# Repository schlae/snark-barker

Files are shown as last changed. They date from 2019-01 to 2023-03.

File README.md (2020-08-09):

# The Snark Barker - a SB 1.0 Clone

The Snark Barker is a 100% compatible clone of the famed SB 1.0 "Killer Card"
sound card from 1989. It implements all the features, including the digital
sound playback and recording, Ad Lib compatible synthesis, the joystick/MIDI
port, and the CMS chips (which are actually Philips SAA1099 synthesizer
devices).

Snark Barker photo

All of the components are readily available. In the bill of materials,
Mouser part numbers are listed where they are available. Chips not available
from Mouser can be purchased from a variety of sources in China.

[Schematic](https://github.com/schlae/snark-barker/blob/master/SnarkBarker.pdf)

[Bill of Materials](https://github.com/schlae/snark-barker/blob/master/SnarkBarker.csv)

Please note that the 0.1" header pins are *not* listed on the BOM. They are
standard breakaway headers (both single and double row). Jumper shunts are
also not listed on the BOM.

[Fab files](https://github.com/schlae/snark-barker/blob/master/fab/SnarkBarker.zip)

Board dimensions are 9.1 x 4.2 inches. When ordering the board, you may want
to specify a card edge bevel (fairly cheap!) and selective gold plating
(expensive!) depending on your needs. The soldermask color can be whatever
you like, but hot pink is preferred.

## The Volume Knob
There don't seem to be any off-the-shelf knobs compatible with the Alps
potentiometer. You may be able to 3D print one based on the model below.
I'd recommend using a high-resolution SLA printer like the Formlabs Form 2.

Fasten it to the potentiometer using an M1.4x0.3mm thread, 6mm long screw
(McMaster-Carr part number 91800A036 or equivalent).

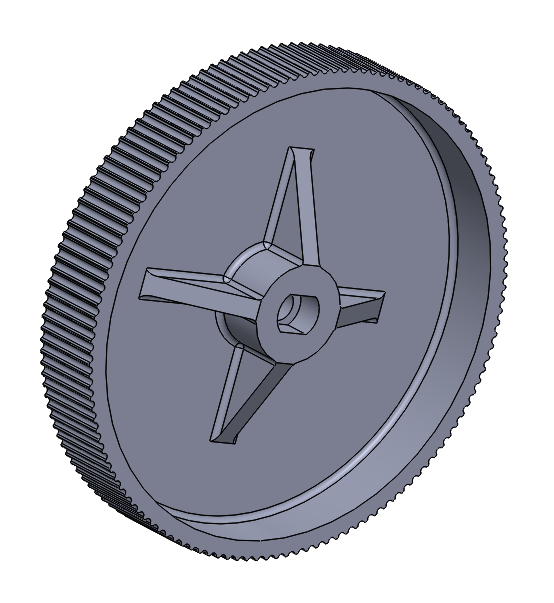
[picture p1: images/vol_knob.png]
Image of the volume knob


[Volume knob STEP model](https://github.com/schlae/snark-barker/blob/master/mech/vol_knob.zip)

Update: I've added a modified volume knob that may print better on FDM
printers.

[Volume knob STEP model, FDM version](https://github.com/schlae/snark-barker/blob/master/mech/vol_knob_fdm.zip)

## The ISA Card Bracket
The bracket specified in the BOM is a blank Keystone 9200 bracket. You will
need to punch or drill holes for the connectors. The KiCad board file has
detailed dimensions showing where to make the holes in the bracket.

I use a chassis nibbler tool to make the square slot for the volume knob as
well as the hole for the DA-15 joystick/MIDI connector. If you are rich,
Greenlee makes a punch for the DA-15 outline.

## The Firmware
There are two ways to get a programmed 80C51 chip for the Snark Barker. One
is to purchase a SB 2.0 DSP chip from China and put it in a 44-PLCC to
40-DIP adapter. This works fine and provides the largest feature set.

Another option is to buy a blank Atmel 89S51 (as listed in the BOM) and
program it with [this HEX file](https://github.com/schlae/snark-barker/blob/master/firmware/sb.hex).

## Assembly Notes
You may wish to socket the two CMS chips, the 80C51 microcontroller, and the
two Yamaha chips.

Be sure to add the 4.7K ohm bodge resistor on top of U5, running between
pins 4 and 14. (Shown below.)

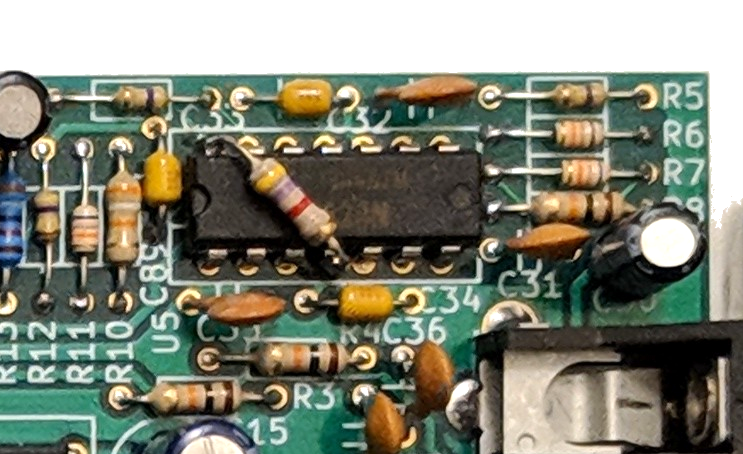
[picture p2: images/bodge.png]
Photo of bodge resistor


For MIDI to work properly, you'll need to solder jumper wires on the headers
marked TXD and RXD (next to the SNARK BARKER logo). Originally these two 3-pin
headers may have been used as a debug port.

Be sure to place shunts in the jumpers marked DRQ1 and JP1, to enable DMA and
the joystick, respectively. Also place shunts to configure the I/O address and
IRQ.

## Testing and Diagnostics
Test your shiny new card using your favorite PC games, or use the [SBDIAG
program that I've written](https://github.com/schlae/snark-barker/tree/master/sbdiag).

## Other Notes
Like the original SB 1.0, the Snark Barker does not need a -5V rail.

## License
This work is licensed under a Creative Commons Attribution-ShareAlike 4.0
International License. See [https://creativecommons.org/licenses/by-sa/4.0/](https://creativecommons.org/licenses/by-sa/4.0/).

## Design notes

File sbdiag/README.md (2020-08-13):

# The Snark Barker Diagnostic Program
Have you built a Snark Barker but it doesn't work right? Having trouble
figuring out exactly what is wrong? SBDIAG may be able to help!

## Usage
* Download the executable along with TADA.WAV and copy it to your vintage
system.
* Run SBDIAG.EXE
* Hit the number keys to pick a menu option
* Hit escape to go up one menu level or to quit.

## Troubleshooting
Unlike games and other software SBDIAG makes no assumptions about what is or
is not working on the hardware. The following few sections provide some basic
troubleshooting advice, primarily geared towards the Snark Barker, although
SBDIAG can be used with any Sound Blaster compatible sound card. It helps
to have the [schematic](https://github.com/schlae/snark-barker/blob/master/SnarkBarker.pdf) in front of you so you can follow along.

### SB DSP
The DSP is actually an 8051 microcontroller. It communicates with the host PC
using two latches that form a simple mailbox.

The first test on the menu, **DSP Address Test**, allows you to check the
address decode circuitry on the sound card. Run the test, and put a logic
probe or oscilloscope on pin 10 of U8 to confirm that the DSPRD\_CS# signal
is pulsing. You can also check pin 3 of U16 for the CARD\_SELECTED# signal.
Furthermore, check pin 3 of U27 to make sure ISA\_RD# is pulsing.

The **DSP Write Test** just writes the "disable speaker" command
in a loop. You can check pin 11 uf U18 (ISA\_WRITE#) to make sure the control
logic is sending the signal to the mailbox latch. If the DSP is alive, then
pin 1 of U18 (DSP\_READ#) will assert when the DSP tries to read the command.
Check pin 28 of U13 for the DAV\_DSP signal, which lets the DSP know that a
byte is waiting for it in the mailbox.

**DSP Reset** does what it says, pulsing the reset line on the DSP (pin 9 of
U13). If you don't see such a signal, backtrack through the reset logic of
U29, U30, U26, and W24.

**DSP Version** retrieves the two-byte version number of the DSP firmware.
If this returns a number that makes sense (like 2.02) then you know that the
DSP mailbox is working and the DSP is programmed correctly.

**DSP Interrupt** tests the interrupt logic by commanding the DSP to assert
the IREQUEST line (pin 12 of U13). You should see this line pulsing during the
test. You can also check pin 9 of U26 which is the actual interrupt line. The
RD\_DAV# line, is pulsed when the host PC tries to read 2xEh (the data
available flag) which clears the interrupt flag. This is pin 9 of U28.

**Generate Sine Wave (no DMA)** uses a DSP diagnostic command to generate a
sine wave. This test does not require working a working interrupt or DMA. You
 should hear a tone coming out of the speakers. If not, work your way through
the audio chain starting from U4, R4/R3, U5 (pin 1), and U5 (pin 8). The DAC
(U12) is current based so you will not see audio voltages on the output pin.
You can check for pulses on the incoming data lines (pins 5-12 of U12).

**Generate Sine Wave (DMA)** streams a digitally-generated sine wave to the
DSP using DMA and the interrupt. If you can hear this, then the digital section
of the card is working. If you hear it for 1 second and then silence, the
interrupt is not working.

**Play Digital Audio** this plays a familiar sound through the speaker. :-)

### Ad Lib Tests

The Ad Lib section of the card uses the YM3812 and Y3014 chips to play back
FM-synthesized audio. The **Try to Detect Ad Lib** menu option runs the
traditional detection algorithm that uses the YM3812's internal timer to
set a status bit. This is a good way to check U9's CS# (pin 7),
READ# (pin 6), WRITE# (pin 5), and A0 (pin 4) signals on the YM3812. While
you are there, make sure there is a 3.58MHz square wave on pin 24. If you
don't see a signal on one of those pins, work your way back through the logic
that drives those pins.

**Play Sine Wave** uses the YM3812 to generate a basic 1KHz sine wave. If you
don't hear anything but the Ad Lib was detected OK, check the audio path
starting from the digital CLOCK (U10 pin 5), LOAD (U10 pin 3) and SD (U10
pin 4) signals, moving to the audio output (U10 pin 2), buffer (U11 pin 14),
and mixer (U11 pins 8 and 7). The YM3812 registers are written only once, so
this test is not very useful for checking the YM3812's host interface.

**Play Percussion Loop** is meant for checking digital writes to the YM3812
registers. There are no read operations during this test.

### CMS Chip Tests

The CMS chips (optional) provide Game Blaster compatibility. If you have
installed them, this part of SBDIAG can help you test it. Since the chips
are write-only, SBDIAG has no way to confirm any tests; you will have to
check pins using a logic probe or oscilloscope, or listen for the audio
output.

**Write Loop** tests simply write to a CMS register over and over again. You
will not hear any sound but you can probe for activity on the following pins:

* CS# (pin 2)
* WR# (pin 1)
* A0 (pin 3)
* DTACK# (pin 7)

**Sine Wave** tests generate a 1KHz sine wave through the left channel, right
channel, or both channels at once. These tests write to the registers only
twice, once before the test and once afterwards to shut off the sound, so this
test is not very useful for use with a logic probe.

### SB-MIDI Tests
The Snark Barker, just like older Sound Blaster cards, has a very basic SB-MIDI
mode (not MPU-401 compatible). Not a whole lot of software uses it and the
wiring is incredibly simple (basically just 8051 UART lines wired to the
joystick port). The tests are very simple and just test the port output and
input capabilities. Note that the loopback test will occasionally return
bad values even when it is working OK.

### Joystick Tests
The PC joystick port is very basic and uses a quad timer chip along with a
simple resistor-capacitor circuit to measure the resistance of the joystick
potentiometers.

**Get raw port status** just returns the raw bits that it reads from the
joystick port. If you have a socketed NE558, you can remove it from the socket
and manually jumper the U3 inputs (pins 2, 4, 6, 8, 11, 13, 15, and 17) to
ground in order to verify that the U3 buffer is working and that the address
hardware also works. You can check U3 pin 1 to verify that the address
decoder is working. Also, joystick buttons can be tested in this state.

**Measure joystick potentiometers** performs the standard PC joystick algorithm
and returns the raw counter values for each axis. You can check that the
trigger signal is correctly appearing at the NE558 by checking pin 3 of U1.

## Building
If you want to build SBDIAG, use Borland Turbo C++ version 3.1 under DOS. Be
sure to set the memory model to "large" or it will not be able to play back
digital audio. This program will run in DOSBOX or on a real vintage computer.

## License
This work is licensed under a Creative Commons Attribution-ShareAlike 4.0
International License. See [https://creativecommons.org/licenses/by-sa/4.0/](https://creativecommons.org/licenses/by-sa/4.0/).

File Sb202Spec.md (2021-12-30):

# Snark Barker 2.02 DSP Firmware Specification

This document is a work in progress. It is an attempt to describe in detail the
operation of the Sound Blaster DSP 2.02 firmware. It's not meant to introduce
you to how Sound Blaster cards play back and record audio, but to describe
how the DSP 2.02 firmware itself works, including previously unknown and
undocumented commands.

Some of the previously undocumented commands and features include:
* The RAM playback command, which loads up to 64 samples into RAM and plays
them back over the speaker.
* The RAM test command, which runs a very basic RAM test on the 8051's
internal SRAM.
* The ROM checksum command, which adds up the contents of ROM into a 16-bit
checksum and returns it (with the two bytes swapped!) to the host PC.

# Pin Assignment Table
| Pin | GPIO | Net | Dir | Description |
| --- | ---- | --- | --- | --- |
| 1 | P1.0 | DAC LSB | O | LSB going to DAC output 
| 2 | P1.1 | DAC | O |
| 3 | P1.2 | DAC | O |
| 4 | P1.3 | DAC | O |
| 5 | P1.4 | DAC | O |
| 6 | P1.5 | DAC | O |
| 7 | P1.6 | DAC | O |
| 8 | P1.7 | DAC MSB | O | MSB going to DAC output
| --- | ---- | --------- | --- |
| 10  | P3.0 | MIDI RX | I | MIDI receive data in
| 11  | P3.1 | MIDI TX | O | MIDI transmit data out
| 12  | P3.2 | IREQUEST\# | O | Pulse low to turn on IRQ to PC
| 13  | P3.3 | DSP\_BUSY | O | Set high to tell PC we are busy
| 14  | P3.4 | DMA\_EN\#  | O | Set low to enable DMA requests
| 15  | P3.5 | DREQUEST  | O | Pulse high to ask PC DMA for more data
| 16  | P3.6 | DSP\_WRITE\# | O | (8051 auto sets this to send data to PC)
| 17  | P3.7 | DSP\_READ\#| O | (8051 auto sets this to get data from PC)
| --- | ---- | --------- | --- |
| 21  | P2.0 | MUTE\_EN  | O | Bring high to mute speaker output
| 22  | P2.1 | N/C | |
| 23  | P2.2 | N/C | |
| 24  | P2.3 | N/C | |
| 25  | P2.4 | N/C | |
| 26  | P2.5 | MIC\_COMP | I | Status of mic input: 1=mic \< DAC, 0=mic \> DAC
| 27  | P2.6 | DAV\_PC | I | 1=Data waiting in buffer for PC host to read it
| 28  | P2.7 | DAV\_DSP  | I | 1=Data waiting in buffer for 8051 to read it

## Detailed Pin Descriptions

### IREQUEST
Initial state: high.

Setting this pin low and then high will trigger an interrupt to be sent
to the host PC.

### DREQUEST
Initial state: low.

Set this pin high and then low to trigger a DMA request to be sent to
the host PC.

### DSP\_BUSY
Initial state: high.
Set this pin low when the firmware is ready to receive commands or command
arguments from the host. This pin should be set high while in interrupt
handlers and cleared at the end of the interrupt handler. It should also
go high when a command is received, at least until the command is successfully
latched into the command holding register.

Here's an example sequence.

1. START: set DSP\_BUSY high
2. Preparation, initialization
3. Ready to receive commands. Set DSP\_BUSY low.
4. Command received from host PC. Set DSP\_BUSY high.
5. Parse command byte, dispatch to correct command handler.
6. Command handler requires an argument byte. Set DSP\_BUSY low.
7. Argument byte received from host PC. Set DSP\_BUSY high.
8. Execute command.
9. Done. Go back to waiting for new commands. Set DSP\_BUSY low.

### DMA\_EN\#
Initial state: high.
Pull this pin low to unmask DMA channel requests. This allows the PC's
8237 to transfer data to or from the sound card.

Typically this pin is pulled low when the firmware is ready transfer data
to the host PC. Set the pin high when the entire transfer is completed--i.e.
you run out of samples to play back.

### DSP\_WRITE\# and DSP\_READ\#
These pins are used by the 80C51's external memory access circuitry to
transfer data during a MOVX instruction. They do not need to be touched
at all by firmware.

### MUTE\_EN
Initial state: low

Assert this line high to prevent the DAC output voltage from reaching the
speaker amplifier.

Note that muting and unmuting the DAC output requires a process to prevent
audible pops. See the speaker mute and unmute commands. This line is controlled
only by those two routines (and the start routine that sets it low on boot). 

### MIC\_COMP
This is an input from the microphone input comparator. It outputs a 1 when
the input sample is less than the current DAC value. It outputs a 0 when the
input sample is greater than the current DAC value. It's checked with the
special ADC successive approximation sampling routine.

### DAV\_PC
This pin is high when data is sitting in the output register but the host PC
has not yet picked it up. The pin goes low when the PC reads the data.

By writing to the external output register using movx, this pin automatically
gets set by the hardware.

### DAV\_DSP
This pin goes high when there is data available in the input register from the
host PC. Otherwise, it remains low until the host PC writes to it.

When reading from the external input register using movx, this pin
automatically gets cleared by the hardware.

# List of DSP Commands

Commands are divided into logical groups.

| Upper Nibble | Command Group  |
| --- | --- |
| 0 | Status |
| 1 | Playback |
| 2 | Recording |
| 3 | MIDI |
| 4 | Transfer setup |
| 5 | Playback (RAM) |
| 6 | Reserved |
| 7 | Playback 2 |
| 8 | Silence |
| 9 | Playback (High Speed) |
| A | Reserved |
| B | Reserved |
| C | Reserved |
| D | Miscellaneous  |
| E | Version |
| F | Test |

Each command group checks individual bits in the lower nibble. The checks
often have a priority; entries at the top of the table get executed if the bit
is set, and entries with lower priorities get ignored even if their bits are
set.

Arguments listed for particular commands are single byte only. Often values
are split into high and low bytes.

## Status Group (0x0)
| Lower Nibble Bit | Command | Description
| --- | --- | ---
| 3 | Halt | Enters an infinite loop.
| 2 | Status  | Sends status flags to the host PC. If DMA\_ENABLE\# is low, then the command reenables the timer interrupt.

## Playback Group (0x1)
| Lower Nibble Bit | Command | Argument | Description
| --- | --- | --- | ---
| 3 | Autoinit DMA DAC | None | Starts auto-init DMA playback
| 2 | DMA DAC | Length lo, length hi |Starts regular DMA playback of "length" samples.
| All others | Direct DAC | byte | Immediately loads DAC with provided sample byte

The above DMA commands check additional bits of the command byte as follows:

| Lower Nibble Bit | Description
| --- | ---
| 1 | 1=Use 2-bit ADPCM compression, 0=Normal 8-bit uncompressed samples
| 0 | Read additional argument byte, use as starting reference for ADPCM

## Recording Group (0x2)
| Lower Nibble Bit | Command | Argument | Description
| --- | --- | --- | ---
| 3 | Autoinit DMA ADC | None | Starts auto-init DMA recording
| 2 | DMA ADC | Length lo, Length hi | Starts regular DMA recording
| All others | Direct ADC | None | Immediately reads a sample from the microphone input and returns it as a byte

## MIDI Group (0x3)

| Lower Nibble Bit | Command | Argument | Description
| --- | --- | --- | ---
| 3 | MIDI Write Poll | MIDI byte | Sends provided byte out over MIDI port
| 2 | MIDI UART mode | none | Ignores DSP commands until a DSP RESET. All subsequent data is piped through MIDI in both directions.
| All others | MIDI Read Poll | none | Receives data from MIDI port, returns the raw bytes. End command by sending any byte to the DSP.

The above MIDI commands check additional bits of the command byte as follows:

| Lower Nibble Bit | Description
| --- | ---
| 1 | Timestamp mode. Adds a 24-bit timestamp to the start of the read data that records the time passed since the command started.
| 0 | Interrupt mode. Generates an interrupt if MIDI read data is available.

## Setup Group (0x4)
| Lower Nibble Bit | Command | Argument | Description
| --- | --- | --- | ---
| 3 | Set DMA block size | block len low, block len high | Sets up DMA block length
| All others | Set time constant | time constant | Sets the sample timer to the provided time constant.

## RAM Playback Group (undocumented) (0x5)
| Lower Nibble Bit | Command | Argument | Description
| --- | --- | --- | ---
| 3 | RAM Load | number of ram samples, ram playback count low, ram playback count high, unused, \<samples\> | Loads RAM with samples to play back, up to 64 bytes.  Playback count is the number of times the sample is repetitively played back in a loop.
| 0 | RAM Playback | none | Plays back samples in RAM

The "ram samples" argument contains the number of samples loaded into RAM.
The playback count (high and low) variables tell the sound card how many times
to play back the RAM sample.

## Reserved (0x6, 0xA, 0xB, 0xC)
The reserved command groups fall through to the status group 0 handler *iff* 
the DMA\_ENABLE\# pin is low. Otherwise the command is ignored and the
firmware waits for further commands from the DSP.

## Second Playback Group (0x7)
| Lower Nibble Bit | Command | Argument | Description
| --- | --- | --- | ---
| 3 | Autoinit DMA DAC (ADPCM) | none | Starts auto-init DMA playback
| 2 | DMA DAC (ADPCM) | Length lo, length hi | Starts normal DMA playback

The above DMA commands check additional bits of the command byte as follows:

| Lower Nibble Bit | Description
| --- | ---
| 1 | 1=Use 2.6-bit ADPCM compression. 0=Use 4-bit ADPCM
| 0 | Read additional argument byte, use as starting reference for ADPCM

## Silence Playback Group (0x8)
| Lower Nibble Bit | Command | Argument | Description
| --- | --- | --- | ---
| (Ignored) | Silence playback | Length lo, length hi | Plays back silence.

## High Speed Group (0x9)
| Lower Nibble Bit | Command | Argument | Description
| --- | --- | --- | ---
| 3 | High speed record | none | Starts high speed DMA record mode. Requires DSP reset to exit.
| All others | High speed playback | none | Starts high speed DMA playback mode. Requires DSP reset to exit.

The above commands check an additional bit of the command byte as follows:

| Lower Nibble Bit | Description
| --- | ---
| 0 | 1=Exit after finishing. 0=Continuous until DSP reset.

The playback length is controlled by the current DMA block length. At the end
of a block, the interrupt is always asserted.

## Misc Command Group (0xD)
| Lower Nibble Bit | Command | Argument | Description
| --- | --- | --- | ---
| 2 | DMA continue | none | Reenables DMA and the sample timer
| 3 & !1 | Get speaker status | none | Returns 00 if muted, ff if not muted.
| 3 & 1 | Exit auto-init DMA | none | Cancels an ongoing auto-init DMA operation.
| 0 & !1 | Enable speaker | none | Turns on speaker output
| 0 & 1 | Disable speaker | none | Turns off speaker output
| All others | DMA pause | none| Turns off DMA and halts the sample timer

## Version Group (0xE)
| Lower Nibble Bit | Command | Argument | Description
| --- | --- | --- | ---
| 3 | Test read | none | Returns contents of test byte
| 2 | Test write | byte | Sets test byte to incoming data byte
| 1 | DMA code | byte | Takes byte, runs it through convoluted algorithm, spits it back out.
| 0 | DSP version | none | Returns major version byte (2) followed by minor version byte (2).
| All others | DSP identification | byte | Returns bitwise complement of the incoming byte. 

## Auxiliary Group (0xF)
| Lower Nibble Bit | Command | Argument | Description
| --- | --- | --- | ---
| 3 | RAM test | none | Tests all internal SRAM by setting it to 0xAA and 0x55. Returns 0 if passing or address of failing byte.
| 2 | ROM checksum | none | Returns msb followed by lsb result of 16-bit checksum of the ROM. This routine has an off-by-one bug and increments the counter past the end of the 12-bit address space by one byte. Depending on the 8051, this either wraps back to 0 or continues on into unimplemented memory.
| 1 | Interrupt | none | Triggers an interrupt request
| 0 | Status | none | Returns a byte containing the contents of port2.
| All others | Sine generator | none | Turns on sine wave output mode.

# Operating Descriptions

## Sample rate timer
This is implemented with an internal timer operating in mode 2 which is a timer
with automatic reload. The reload value corresponds to the value provided to
the "Set time constant" DSP command. Since the oscillator frequency is 12MHz,
the clock going to the timer is 1MHz.

## Data transfers
There are two mailboxes in the hardware: one for data going from the host to
the DSP and the other for data going from the DSP to the host. Each mailbox
has a flag that can be checked by the DSP. DAV\_DSP indicates when the host
has placed data in the incoming mailbox and it is safe for the DSP to read it.
DAV\_PC means that there is data in the outgoing mailbox and the host has not
read it yet.

To check for data from the PC, you busy-wait until DAV\_DSP gets set. Then you read the data byte with a MOVX instruction.

## Audio Playback
The sound card plays audio when it receives the playback command (0x14). This
command has the following structure:

1. Clear the DSP\_BUSY pin so that the host knows the DSP can receive
additional data bytes.
2. Check to see if DMA is enabled (DMA\_ENABLE#). If DMA is running (sound is
already playing back) then read a 16-bit value into the shadow length
variable, and then end the command early. The shadow length is how you can cue
up playback for the next playback command.
3. If DMA is not already enabled, then read back a 16-bit value from the host
and store it in the samples remaining counter.
4. Set the DSP busy pin so the host knows that playback is in progress.
5. Clear the DMA\_ENABLE# to ensure that the card can request DMA transfers
from the host.
6. In ADPCM mode, pulse DREQUEST high and wait for an 8-bit value to arrive
from the host. Prime the ADPCM receive buffer with this. In ADPCM reference
mode, instead of storing this byte in the receive buffer, send it to the DAC
output since this is the reference value.
7. Set up the proper interrupt vector for the timer interrupt handler. There
are separate handlers for 8-bit, ADPCM 2 bit, etc.
8. Enable timer interrupts, and turn on the sample timer.

When the timer interrupt triggers, the handler does the following:

1. Set DSP\_BUSY.
1. Check DAV\_DSP. If it is set, then there is a command pending from the
host, so immediately exit the handler. The main loop will handle it.
2. Pulse DREQUEST. Block and wait for a byte to come in. This is our sample.
3. Copy the sample byte to the DAC output.
4. Decrement the samples remaining counter.
5. If the samples remaining counter isn't zero, then clear DSP\_BUSY and exit
the handler.
6. Otherwise, check to see if the autoinit exit flag is set (controlled by the
exit autoinit DSP command). If so, then clear the autoinit exit flag, the dma
mode flag, and the autoinit mode flag. Clear the timer enable, turn it off,
pulse the host interrupt control line IREQUEST#, and set DMA\_ENABLE#. Exit
the handler.
7. Check the dma mode flag. If it's on, turn it off, turn off the autoinit
flag, then copy the shadow length over to the samples remaining counter. Pulse
the host IRQ IREQUEST#, clear the DSP\_BUSY pin, then exit the handler.
8. Check the dma autoinit mode flag. If it's off, then bail just the same way
that the autoinit exit flag ends the handler (clears flags, etc).
9. Otherwise copy the stored dma block length value to the samples remaining
counter. Pulse IREQUEST#, clear the DSP\_BUSY pin, and exit the handler.

## DMA Recording
The process of DMA recording is nearly identical to playback. The
initialization routine first has to mute the speaker since the DAC is shared
with the playback hardware.

In the timer interrupt handler, the firmware performs the ADC algorithm to get
a valid sample and places it in the mailbox for the PC DMA controller to read
it, then pulls the DREQUEST line to let the DMA controller know.

The ADC algorithm is a successive approximation technique that begins by
loading the half code value into the DAC. By looking at the comparator output,
the firmware chooses whether to use the upper half or the lower half of the
current partition, then divides that partition again, checking the comparator
again to decide which half to use, and so on and so forth until 8 bits have
been acquired.

Note: The DMA ADC command checks to see if DMA is already running. If so,
then it loads the length argument into length\_low (not used by the running
DMA operation). Otherwise it loads it into len\_left\_lo (Same for the high
byte.) This is so that you can queue up the length of the next set of samples
to record if DMA is already running, and get a glitch-free recording that
spans multiple DMA operations. 

## MIDI

This is not MPU-401 compatible--it is known as SB-MIDI mode. The firmware
configures the internal UART to use the standard MIDI baud rate and sets
up a 64-byte receive buffer. While in the Read Poll or MIDI UART command modes,
any bytes coming in on the serial port are placed in the receive buffer, which
uses the usual two pointer technique to maintain a read and write pointer.
As the host PC reads bytes, they are removed from the receive buffer.

The MIDI UART command never returns and requires a DSP RESET write. Basically
it immediately transmits any bytes received from the host PC over the UART,
and buffers any received UART bytes for the host PC.

### Timestamp mode
This mode bit, when set, uses the internal timer, set to tl0=17h, th0=fch.
When the timer overflow occurs, the ISR increments a 24-bit counter. This
counter gets output when you read MIDI data. It comes out as little-endian,
(low, mid, high bytes) followed by all MIDI data in the buffer. The counter and
timer get cleared when you run a MIDI read command, so it effectively gives you
the time delay between when you sent the DSP command and when the first data
comes back. These 3 bytes are stored in the same 64-byte buffer as the incoming
MIDI data.

When you run a MIDI command in timestamp mode, it sets a flag that is checked
in the timer interrupt handler. This flag is cleared when the command
terminates. The interrupt handler, if it sees the flag set, increments the
24-bit counter and resets the timer value to fc17h. This interrupt activity
replaces all other interrupt activity, which is why you can't play back or
record audio during MIDI transactions.

## Sine Wave Mode

TBD.

# Timer Interrupt Handlers

The timer interrupt handler depends on the current mode of the card. High speed
mode is checked first to minimize the interrupt latency.

| Handler | Description
| --- | ---
| MIDI timestamp | Increments the 24-bit MIDI timestamp counter
| High speed | Handles high speed mode DAC and ADC
| DMA DAC8 | Outputs 8-bit uncompressed samples
| DMA DAC ADPCM2 | Outputs 2-bit ADPCM samples
| DMA DAC ADPCM4 | Outputs 4-bit ADPCM samples
| DMA DAC ADPCM26 | Outputs 2.6-bit ADPCM samples
| DAC silence | Outputs silence
| DMA ADC | Captures 8-bit uncompressed samples
| RAM playback | Plays back 8-bit uncompressed samples from RAM
| Sine | Plays back sine wave samples

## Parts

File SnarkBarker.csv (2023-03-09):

Item | Qty | Reference(s) | Value | Mouser
1 | 13 | C1, C14, C30, C38, C39, C42, C43, C44, C45, C46, C55, C87, C88 | 10uF 16V | 667-ECA-1CM100I
2 | 2 | C2, C13 | 47uF 16V | 667-ECA-1CM470I
3 | 7 | C3, C7, C12, C15, C17, C18, C40 | 100uF 16V | 667-ECA-1CM101I
4 | 2 | C4, C11 | 470uF 16V | 667-ECA-1CM471B
5 | 31 | C5, C6, C8, C9, C10, C16, C19, C33, C34, C47, C48, C50, C53, C56, C69, C70, C71, C72, C73, C74, C75, C76, C77, C80, C81, C82, C83, C84, C85, C86, C89 | 0.1u | 581-SA105E104M
6 | 10 | C20, C21, C22, C23, C24, C25, C26, C27, C28, C29 | 0.01u | 810-FG28X7R1H103KNT0
7 | 7 | C31, C36, C37, C49, C54, C63, C78 | 1000p | 810-FG28X7R1H102KNT6
8 | 5 | C32, C35, C52, C64, C79 | 330p | 810-FG28C0G1H331JNT6
9 | 2 | C41, C59 | 47p | 810-FG28C0G1H470JNT6
10 | 3 | C51, C58, C60 | 2200p | 810-FG28X7R1H222KNT6
11 | 1 | C57 | 4700p | 810-FG28C0G1H472JNT6
12 | 2 | C61, C62 | 30p | 810-FG28C0G1H270JNT6
13 | 2 | C65, C68 | 270p | 810-FG28C0G1H271JNT0
14 | 1 | C66 | 680p | 810-FG28C0G1H681JNT6
15 | 1 | C67 | 470p | 810-FG28C0G1H471JNT6
16 | 2 | D1, D2 | 1N4148 | 512-1N4148
17 | 1 | DRQ1 | DMA ENABLE JUMPER | -
18 | 1 | IO1 | I/O ADDX | -
19 | 4 | IRQ2, IRQ3, IRQ5, IRQ7 | Conn_02x01 | -
20 | 1 | JP1 | JOYSTICK EN | -
21 | 3 | L1, L2, L3 | BEAD | 623-2743004111
22 | 1 | MIC1 | Microphone | 490-MJ-3536N
23 | 1 | P1 | Joystick/MIDI | 636-182-015-213R531
24 | 1 | P2 | L7809 | 511-L7809CV
25 | 2 | R1, R2 | 270 | 603-CFR-25JB-52-270R
26 | 9 | R3, R4, R8, R23, R24, R34, R36, R37, R40 | 10K | 603-CFR-25JB-52-10K
27 | 3 | R5, R9, R12 | 470K | 603-CFR-25JR-52470K
28 | 3 | R6, R7, R11 | 68K | 603-CFR-25JB-52-68K
29 | 1 | R10 | 39K | 603-CFR-25JB-52-39K
30 | 1 | R13 | 39.0K 1% | 603-MFR-25FBF52-39K
31 | 1 | R14 | 100.0K 1% | 603-MFR-25FBF52-100K
32 | 2 | R15, R16 | 470 | 603-CFR-25JB-52-470R
33 | 1 | R17 | 33K | 603-CFR-25JB-52-33K
34 | 1 | R18 | 1.5K 1% | 603-MFR-25FBF52-1K5
35 | 3 | R19, R20, R21 | 390 | 603-CFR-25JB-52-390R
36 | 3 | R22, R25, R27 | 27K | 603-CFR-25JB-52-27K
37 | 6 | R26, R39, R41, R42, R44, R_BODGE1 | 4.7K | 603-CFR-25JB-52-4K7
38 | 2 | R28, R31 | 15K | 603-CFR-25JB-52-15K
39 | 2 | R29, R30 | 47K | 603-CFR-25JB-52-47K
40 | 2 | R32, R33 | 1.5K | 603-CFR-25JB-52-1K5
41 | 1 | R35 | 2.2K | 603-CFR-25JB-52-2K2
42 | 1 | R38 | 2.70K 1% | 603-MFR-25FBF52-2K7
43 | 1 | R43 | 1K | 603-CFR-25JR-521K
44 | 1 | RP1 | 2.2K | 652-4608X-AP2-222LF
45 | 2 | RP2, RP3 | 1K | 652-4605X-AP1-102LF
46 | 2 | RXD1, TXD1 | Conn_01x03 | -
47 | 1 | S1 | OUT | 490-SJ1-3553NG
48 | 1 | S2 | ALPS_RK08H_DUAL | 688-RK08H12100F3
49 | 2 | T1, T2 | 2N3904 | 833-2N3904-AP
50 | 1 | U1 | NE558 | -
51 | 1 | U2 | 74LS245 | 595-SN74LS245N
52 | 1 | U3 | 74LS244 | 595-SN74LS244N
53 | 1 | U4 | TEA2025B | -
54 | 1 | U5 | LM324 | 595-LM324AN
55 | 1 | U6 | LM393 | 595-LM393P
56 | 2 | U7, U8 | 74LS138 | 595-SN74LS138NE4
57 | 1 | U9 | YM3812 | -
58 | 1 | U10 | YM3014B | -
59 | 1 | U11 | NJM3403A | 513-NJM3403AD
60 | 1 | U12 | MC1408_DIP | 926-DAC0808LCN/NOPB
61 | 1 | U13 | 805X | 556-A89S51-24PU
62 | 2 | U14, U15 | SAA1099 | -
63 | 3 | U16, U25, U28 | 74LS08 | 595-SN74LS08N
64 | 1 | U17 | 74LS139 | 595-SN74LS139AN
65 | 2 | U18, U19 | 74LS374 | 595-SN74LS374N
66 | 4 | U20, U22, U23, U26 | 74LS74 | 595-SN74LS74AN
67 | 1 | U21 | 74LS125 | 595-SN74LS125AN
68 | 3 | U24, U27, U30 | 74LS32 | 595-SN74LS32N
69 | 1 | U29 | 74LS14 | 595-SN74LS14N
70 | 1 | XTL1 | 12MHz | 815-AB-12-B2
71 | 3 | ZD1, ZD2, ZD3 | 5.1V Zener | 78-1N5231B-TAP
72 | 1 | - | Bracket Mount | 534-9200

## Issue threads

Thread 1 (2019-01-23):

PCI Express version is unavailable

ghost, 2019-01-23:
Hello,

This is obviously a joke. I don't know what effort it would take to build such a device.

Congratulation on your impressive work.

Best regards.

eflukx, 2019-01-26:
Probably it would be "easiest" to employ a PCIe-to-ISA bridge.
An Axis AX99100 probably would do the job (?), another possible approach would be to implement the bridge in an FPGA (Xilinx seems to have the IP cores available to do something similar!)

root42, 2019-02-27:
Problem with PCIe is that iirc ISA DMA and IRQs will not work with such an adapter… But yeah, a PCIe version would be impressive :)

volkertb, 2019-02-28:
A Micro Channel (MCA) version would be awesome, though, especially given how rare it is to find sound cards for that architecture. 😄 But given that it's a proprietary bus with less public documentation and only a few systems that support it, I reckon it would be a lot harder to design one than the ISA version was. I guess I should open a separate issue for that, right? 😉

root42, 2019-02-28:
MCA would be cool, yes. But you need a proprietary interface IC. It seems many cards used the 82c611. However I doubt these are available easily from any of the Chinese suppliers, who sell obsolete ICs...

volkertb, 2019-03-01:
Interesting. I guess it made sense that a more complex bus would require a dedicated interface controller. Perhaps such a 82c611 or 82c612 chip could be salvaged from another cheap MCA expansion card. MCA sound cards go for hundreds of dollars on eBay due to their rarity, but I see a lot of MCA NICs going for around $30. Data sheets can still be found on-line through some quick googling, so based on that, someone savvy enough might be able to design a sound card that would work on PS/2 systems based on the Micro Channel Architecture. But this would be a **very** niche project, even more niche than a retro ISA sound card. And well beyond my knowledge and skills, I'm afraid. 😅

mikedebian, 2019-07-28:
https://threadreaderapp.com/thread/1153718213449904128.html

Interesting read about TPM to ISA (shoutout to this project as well.)

NukemD, 2019-08-01:
> A Micro Channel (MCA) version would be awesome, though, especially given how rare it is to find sound cards for that architecture.  But given that it's a proprietary bus with less public documentation and only a few systems that support it, I reckon it would be a lot harder to design one than the ISA version was. I guess I should open a separate issue for that, right?

There's already a working solution for machines with proprietary slots or without slots at all (ie. laptops or thin clients) called OPL2LPT or the more recent OPL3LPT. It's basically a sound card for the parallel printer port and uses a TSR to reroute port calls. It has very good compatibility with games which don't run in protected mode (DPMI) and decent compatibility mode with games that do via patches.

https://www.serdashop.com/OPL3LPT

volkertb, 2019-08-10:
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

I'm aware of the OPL2LPT and OPL3LPT products and they are indeed amazing. However, they only provide an alternative for the FM (music synthesizer) part of Sound Blaster emulation/compatibility. Having a sound device that would plug into a single parallel port while providing compatibility or emulation of both FM synthesis and DAC playback would be ideal. Such devices have been released in the past, but they are hard to find and expensive. Having such a device with an open source design, that would be great.

Closed 2021-12-30.

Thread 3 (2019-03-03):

Do you aslo develop a windows driver for it?

jeditobe, 2019-03-03:
Do you aslo develop a windows driver for it?

ReactOS project needs your knowledge and experience  https://github.com/reactos/reactos

volkertb, 2019-03-09:
Since this card is intended to be a 100% compatible replica of the original SB 1.0 card, the existing drivers available for that card should work this card without any modifications. Or do you mean drivers for modern Windows versions? That might prove problematic, since (as far as I have understood), newer Windows versions no longer provide support for ISA-based expansion cards. But I'm sure someone else here can correct me if I'm wrong or misunderstood the question.

NukemD, 2019-07-30:
The Sound Blaster 1.0 was released in 1989, about a year before the first widely used version of Windows was released (3.0). It was never designed with Windows support in mind, it was purely a DOS sound card.

It doesn't make sense to write a driver for an ancient 8 bit ISA sound card for an OS that would be crippled by it. ReactOS targets Windows XP compatibility, and machines of the time period had already pretty much eliminated ISA slots. The few that did have ISA often had limitations that would break support for the card, like lacking DMA support.

Even assuming you had a weird setup to use the card, you'd have to write special software to take advantage of the card. It was primarily designed for FM synthesis by utilizing a YM3812 and could only sample monaural PCM audio at 8 bit 23 kHz.

Closed 2020-11-14.

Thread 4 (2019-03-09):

What is the IP and license situation of the sb.hex firmware?

volkertb, 2019-03-09:
First of all: this is a great project. For both tinkering and historic purposes. Thanks for working on this and sharing the fruits of your labor with us. 😃

However, I have a concern about the sb.hex binary firmware blob that is included in this code base. Has this been released as freeware by the original owner(s)? Do we even know who owns the IP rights to it? And is the source code to that firmware also available by any chance?

Alternatively, perhaps it would be a useful and interesting project in itself to develop a clean-room open source firmware for the Snark Barker (and possibly also for other SB clone implementations) that would be open source, full-featured and perhaps even free of the quirks that plagued the original SB products back in the day, such as lack of click-free seamless DMA playback capability, etc? But that would of course deserve its own GitHub project.

Anyway, a clarification of the license terms under which the sb.hex firmware has been made available and included in this project would alleviate some concerns w.r.t. legality. Thanks.

raszpl, 2020-11-11:
xxd -r -p sb.hex > sb.bin
    strings sb.bin

    lot of garbage
    (C)19k
    92 Anchor Electronics Co.,

ZhuHai Anchor Electronics Co.,LTD, I dont think they exist anymore.

volkertb, 2020-11-14:
That doesn't mean it's public domain now.

Wouldn't it be better to develop an open source replacement firmware? One that is not only guaranteed to be Free, but also maintainable?

schlae, 2020-11-14:
are you volunteering? (please say yes!) here's the [firmware spec](https://github.com/schlae/snark-barker/blob/master/Sb202Spec.md).

raszpl, 2020-11-14:
> That doesn't mean it's public domain now.

its abandonware

ChrisBlizz, 2020-11-25:
I'd be interested in knowing how the sb.hex firmware blob was acquired. Was it dumped somehow? I read somewhere that the firmware of the Intel micros Creative used for their DSP was usually not dumpable/readable. Just curious.

elosha, 2021-01-21:
@ChrisBlizz You read correctly. It has been dumped from a SB clone board of that time, where the manufacturer either forgot to use the readout protection or used a version of 8051 without protection. It's not the original Creative firmware but an alternative which does the same things.

There may be (illegal) ways to read the Creative firmware though. Intel once sold a 8051 preprogrammed with a BASIC interpreter. It was of course protected … but still, copies of the BASIC interpreter ROM exist on the net ;)

raszpl, 2021-01-21:
https://github.com/schlae/sb-firmware

klench04b, 2021-11-15:
Hello, I am building the snarkbarker for myself. I would like to get help with the hex file because I don't know if I created the hex file from the github data correctly. What I did was I cut and pasted the github file hex file info into notepad and saved it as a .hex file. I have an IC programmer. Once I select the right IC in the programmer do I simply load the .hex file I created to flash the chip? I'm used to using .bin files to flash so i don't know what I'm doing with the hex files. When I tried to download the hex file from the repository here the programmer didn't load the hex file because it was seen as an error, so that's when I opened the file in github, copied and pasted into notepad and saved as a .hex file. Did I create the hex file right in order to flash the IC? Thanks. I've attached a screenshot of snarkbarker.hex I created with the file opened in notepad.
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

Closed 2021-12-30.

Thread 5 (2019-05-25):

I'm buying boards and components, who will join?

eflukx, 2019-05-25:
### TL;DR

**We're (group) buying all parts for the SnarkBarker, that I will ship out @cost. There are 3 sets (of 10) left, so please let me know if you want to join in!**

---
_Original message_

Excuse me for spamming the issues section, but this might be of interest of people following this repo:

I have ordered (and received) 10 very nice bare SnarkBarker PCB's, but I only need one :) I'm planning to order rest of components soon to build my SnarkBarker, but happily order more parts for whomever interested.

If you're interested in joining up: I will ship PCB's + components @cost (expect around EUR50) across Europe (from Netherlands).

Let me know!

northern, 2019-05-25:
I'll join. What's the total cost of a single board, i.e. PCB & components? I might be interested in a package for 2 or 3 depending on price. I'm based in Australia.

romsom, 2019-06-26:
Thanks for making the offer!
If I'm not too late, I'm in for 2 as well! :)

raynet, 2019-07-07:
I would gladly take 1 if still available

eflukx, 2019-07-07:
Hi Guys.. I see there's some interest.. Cool. :) Yep the offer is still up, haven't really got time do do something with this; really busy with some other important stuff..
But will get this moving soon.

@northern  are you still in? Shipping to Australia will be ~50 AUD
@romsom  and @raynet where will you need the shipment?

romsom, 2019-07-07:
@eflukx That's great news :)
In my case shipping would be to Germany.
Do you plan on buying pre-programmed 8051s?
I'm asking because I have access to a programmer and could easily program the 10 AT89S51s if that could reduce the price and/or effort to source the parts.

northern, 2019-07-08:
@eflukx Hi there! Yes, still interested. Do you have an indication of total cost (without shipping), just to get an idea. @romsom brought up a good point regarding the pre-programmed 8051s. Could you elaborate on the what would be required on my end (as the receiver) other than soldering?

Thanks again for your efforts so far, much appreciated.

raynet, 2019-07-08:
@eflukx  In my case shipping is to Finland.

eflukx, 2019-07-08:
Ha.. I didn't think of the programming of the 8051.. :) I see Atmel has been so kind to include an ISP programming facility into this baby (reading the datasheet really is a trip down memory lane.. a uC with absolutely zilch peripherals.. soo cute.. 😸 ) I have some (actually quite a lot.. 😉 ) programmers of sorts around here, so I think I can manage to get you all a pre-programmed AT89S51! I dont think my "official" AtmelICE  will do the job, but it seems a $2 usbasp (with modified firmware) _will_ actually do the job.

I see we now have interest (including me) for about 7 kits. I'll get pricing for all of you by the end of this week. The volume knob I'll print for free :)

romsom, 2019-07-08:
That's awesome, thank you very much! :)
Hehe, cheap tools with open/hackable firmware are the best! :)

patricklaf, 2019-07-09:
Hello,
I am interested in one for France if possible.

eflukx, 2019-07-09:
@patricklaf Ok.. put you on "the list" :)

eflukx, 2019-07-09:
Hi guys, here's a price indication:

Apart from shipping costs (and duties, where applicable), the sets will cost apx. 50 EUR when I order 10 sets:

- PCB Cost ~ 10 EUR
- Ebay parts ~ 6 EUR
- Mouser parts ~ 35 EUR
- 3D printer volume knob FREE :)
- IC sockets **not** included
- Blind ISA bracket included, please drill/dremel yourself.. :)

raynet, 2019-07-09:
Sounds great

eflukx, 2019-07-09:
Pro tip: I _love_ the [KiCad iBOM plugin](https://github.com/openscopeproject/InteractiveHtmlBom), the interactive manual assembly helper tool
.
Attached the iBOM HTML export for the SnarkBarker: [snark_barker_ibom.zip](https://github.com/schlae/snark-barker/files/3374971/snark_barker_ibom.zip)

romsom, 2019-07-09:
@eflukx You should just have received the payment for 2 boards (rounded up) :)

eflukx, 2019-07-09:
> @eflukx You should just have received the payment for 2 boards (rounded up) :)

Yep, just got email from paypal, thanks!

northern, 2019-07-10:
@eflukx I will transfer payment tonight when I come home (tomorrow morning for you). Can email you on the email address that's on your Github profile to get your PayPal details? I'm in the run for 2 kits.

eflukx, 2019-07-10:
Ok gents,

Got confirmation of @northern (2 sets) and @romsom (2 sets). When I get 2 more orders, I'll place the order at Mouser for the 10 sets! That means if @patricklaf  and @raynet chip in as well, I'll order very soon!

Shipments from Mouser typically takes a couple of days to come in (apart from the potentiometer that is back-ordered). Please be aware that some of the parts are NOS (new old stock), which I ordered from Ebay. Shipping will take some more time, I expect that will take ~1 - 1.5 months from now for the NOS parts to come in, after which I;m able to complete the sets. So a bit of patience is required.. ;)

Ps. Please share your **shipping addresses** via the same email account as the PayPal account.

Ps. I can not guarantee the quality of the NOS parts. Typically these parts work just fine, the not-so-expensive parts like these tend to be OK and not counterfeits, but I have seen differently! Probably I'll just build one of the SB's myself (share some pictures in this thread) to see if all is working as expected. (hmm.. need to dust off an old ISA machine.. )

raynet, 2019-07-10:
@eflukx I will take part too

eflukx, 2019-07-11:
@northern, I got your payment! (seemed to have missed the email earlier). The amount seems correct, but PayPal has deducted a 7,64 fee. (Probably you selected "pay for goods" instead of "pay friends and family) I'll update the for the final amount when I ship the set out to you!

@all Please don't forget to send me your shipping details per email!

**As I have the 6 paying participant, I'll place the parts order @mouser!**

northern, 2019-07-11:
@eflukx :man_facepalming: Ah, sorry mate. No worries, lets fix it up before you ship out.

eflukx, 2019-07-17:
Hey, look what the cat dragged in...

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

It's a Mouse(r)!

Sjaakafhaak, 2019-07-21:
Wel printer guy here.
I did some magic to the printer and as a matter of fact the look much nicer now.
And the ridges on the edge are pretty nice.

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

Also they are black like they should be :).

eflukx, 2019-07-27:
Hi guys here's a short update of the parts delivered and stuff we're still waiting on...
Most of the stuff is in already, but some items are back-ordered and some EBay (N)OS parts are still somewhere between China and Europe..  ✈️ 🚢

## Stuff i did receive
- [x] 3D Printed volume knobs
- [x] Most of the Mouser parts
- [x] Nice PCB's

## Stuff I plan to do myself before shipping
- [ ] Program all AT89S51 µC's
- [ ] Build one full board
- [ ] Test above board

## Mouser back ordered items
- [ ] S2 - Alps RK08H (10k dual potentiometer)
- [ ] S1 - CUI SJ1-3553NG (3.5mm audio jack)
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
eflukx, 2019-08-16:
@Toesoe Yep I have some kits left.. You came at the right time as essentially all components are in (except for a small counting mistake Mouser made, but will be fixed soon!)

Kit price is EUR 60,-- w.o. shipping. So, say 67,-- incl. shipping within NL.

Ps. Ophalen in Den Haag / Rijswijk kan ook!  Krijg je ook koffie :)

Toesoe, 2019-08-30:
@eflukx and others, after designating myself as a guinea pig I'm glad to say that (even with my crappy soldering) all parts work as intended, both the YM3812 and the SAA1099's! Had to program the AT89S51 with an old Arduino and ran into a few issues with my 166MHz AMD K6 being too fast for the card, but disabling L1 cache helped a lot (tip). It sounds excellent! https://imgur.com/a/48dfVgK

eflukx, 2019-09-13:
@Toesoe Good to see you have your board working! Cool! 🥇 Thanks for your feed back on this. Let's consider this _the_ successful validation test: so I can cross that off my checklist ✔️

@all Sorry for the loooong delay from my side. I have been quite busy coming back to work after summer vacation. Wasn't able to allot much time to the SnarkBarkers.. I _do_ have all your components sorted en ready to ship!

Somehow I'm having trouble with programming the 8051.. I tried different programmers: multiple USBASP's and an Arduino), at least 3 different versions of the USBASP firmware, multiple versions of AVRDude (real version hassle, apparently different versions have different config file layouts) and other programming tools, tried several different AT89S51's, different oscillator crystals, reset pin invertors yea/nea, different PC's, different bread boards... all to no avail. *sigh* The god's don't seem to be with me on this one.  :godmode: (Most frustrating is that all "other" peoples in the interwebz don't seem to have any problem with programming this baby...) (@toesoe will be in touch with you in your setup)

To prevent further delays, I'll start shipping soon (expect this weekend/beginning next week). Albeit with a virgin-like so some programming to do yourself.. ;) All that have paid up front I'll send you the tracking info by email.

northern, 2019-09-25:
Hi @eflukx. Thanks for the update and apologies for the slow response. Sorry to hear you're having issues programming the 8051. If you feel it can't be done or you can't find the time then I guess you might as well send the components out. I don't really have any experience doing this kind of thing but I will give it a go. I think I still owe you some money for postage. Can you let me know how much that this so I can wire it to you?

Again, thanks for all you efforts so far. Very much appreciated!

Toesoe, 2019-09-25:
For anyone looking to go the Arduino route, I sketched out the setup I used for as far as I remember it (it's been a couple of weeks :smile:). All the passives are available in @eflukx's kit.
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
I used a cheap Chinese UNO clone that I've had lying around for, what, 6 years or so?
Add [the following](https://pastebin.com/Dkh2Yzix) to your avrdude.conf (it works for my version `6.3-20171130`), upload the ArduinoISP sketch and run avrdude with `-c stk500v1 -P <port> -p 89s51 -b 19200`. If it's detected properly, add `-U flash:w:sb.hex` to write the blob to the MC.

raynet, 2019-10-22:
Got my kit, now just need to find time to build it :)

patricklaf, 2019-10-23:
I have received the kit! Very nice printed knob and a lot of things to solder... Thank you all for making this possible.

eflukx, 2019-10-23:
Actually haven't found the time to solder my own.. 😓 😉 💨
@romsom You should have yours too..
@northern Your's was sent out at the same time, but probably takes a little longer to reach other end of the world.. 😉

patricklaf, 2019-10-24:
I programmed my AT89S51 with my TL866CS without any problem.
If you have difficulty, you can send me your MCU, I will program it and send it back to you.

romsom, 2019-10-24:
@eflukx Yes it's here! Thanks! :)
Haven't had the time to dig through it, though.
At least my trusty old Win95 machine is ready to be set up and program the AT89S51s ;)

northern, 2019-11-02:
@eflukx Picked up the kits from the post office today. Thanks for taking great care with the shipping and  also thanks again for putting all this together. Hopefully I have some time over the xmas period to tinker with this a bit more. :)

eflukx, 2019-11-03:
Cool, so everybody seem to have gotten their kits! That took a while to reach you @northern ! Happy it reached its destination 😄
Apparently I'm the only one having troubles programming the 8051 in the end.. 😂 Will give it another try when I get 'round to build my own Snark Barker!
@all keep us posted (here) with the building result!

Closed 2019-11-03.

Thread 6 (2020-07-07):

Questions about 80C51/DSP

elosha, 2020-07-07:
I'm totally looking forward to build a Snark Barker. I am very curious and have a few questions about these sentences:

> There are two ways to get a programmed 80C51 chip for the Snark Barker. One is to purchase a SB 2.0 DSP chip from China and put it in a 44-PLCC to 40-DIP adapter. This works fine and provides the largest feature set.

1. Does 'largest feature set' mean SB 2.0 instead of SB 1.0 specifications; and if so, which features of the Snark Barker will change? Or is the 80C51 firmware missing DSP features?

> Another option is to buy a blank Atmel 89S51 (as listed in the BOM) and program it with this HEX file.

2. Will any 8051 or 80C51 with 8KB of ROM work, or do we require any of the newer Atmel features?
3. Was the original DSP from Creative based on a 80C51, too?

Thank you for answering and your impressive work, maybe you can even add the info to [README.md](https://github.com/schlae/snark-barker/blob/master/README.md).

schlae, 2020-07-07:
DSP 2.0 gives you auto-init DMA and a high speed playback mode. It's also the original DSP so it is exactly compatible. The other image in the repo is from a knockoff and, although it too supports auto-init DMA and high speed playback, may not be 100% compatible. I have no way to verify that it is.

No new Atmel features are required, so you could use an 80C51 (technically an 87C51 since the 80C51 is mask-ROM only) from any number of different vendors. The Atmel part is the one that I tested with.

elosha, 2020-07-08:
Great, thank you for your quick reply. I read about auto-init DMA (crackle-free playback) und high-speed playback (44.1KHz) now and they seem like worthy improvements to have. But that knockoff image is missing in the repo.

Regarding compatibility of the knockoff, are there known problems or do you simply not want to guarantee the same level of compability?

Would it be possible to simply dump an original DPS 2.0?

schlae, 2020-07-08:
The image is [here](https://github.com/schlae/snark-barker/blob/master/firmware/sb.hex).

elosha, 2020-07-08:
Thanks, I thought this was the 1.0 DSP featureset image.

Closed 2020-11-14.

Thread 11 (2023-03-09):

Replacement for obsolete Mouser parts (152-3415, 512-LM324AN)

anetanel, 2023-03-09:
I'm gathering the parts for a card, using the BOM file in Mouser, but there are 2 items that are marked as obsolete, so I'll need replacements.
1. The 15 pin D-SUB socket ([152-3415](https://www.mouser.co.il/ProductDetail/?qs=oQGaBZOgWEYA4BkUeyODRg%3D%3D))
2. The amplifier chip U5 ([512-LM324AN](https://www.mouser.co.il/ProductDetail/?qs=AFLC8Sm4xaWh3GAKvNiiWg%3D%3D))

I tried looking for a replacement DSUB connector by selecting all the attributes and looking for similar, and the search came up with [20 items](https://www.mouser.co.il/c/connectors/d-sub-connectors/d-sub-standard-connectors/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). Can I just grab [the cheapest one](https://www.mouser.co.il/ProductDetail/HARTING/09682537612?qs=8yNGYH%2FU%252B5LaO0VSntI2kw%3D%3D)? :P

And can the amp chip be replaced with this one: https://www.mouser.co.il/ProductDetail/Texas-Instruments/LM324AN?qs=KaAwwOlwapuGsi7hHRxlkw%3D%3D ?
I noticed that it have a bit different "Output Current per Channel" value of 20mA, vs 40mA in the original part.

schlae, 2023-03-09:
i've swapped in some new parts in the BOM. the TI LM324 should work fine. the d-sub connector is not critical but you must check the distance between the mounting holes on the footprint and the panel edge -- it should be about 9.5mm. some d-subs are "stubby" and won't work.

Closed 2023-03-09.

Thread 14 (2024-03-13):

DSP clarification is required

rkurbatov, 2024-03-13:
Hello and, first of all, thanks for this amazing project.

While I'm waiting for all the remaining parts to arrive, I'd wanted to clarify the DSP functionality.

As I understand, original SB 1.0 had DSP version 1.x that allowed 22kHz playback
SB 1.5 was the same card with C/MS chips removed for the price reason (btw board rev. CT1320C is actually that 1.5 version if I'm not mistaken)
SB 2.0 used custom creative chip instead of plenty discrete logic chips and 8051 (idk if it had 8051 core inside). It supported 44.1 kHz, auto init DMA and its DSP version was 2.01+.
Then DSP 2.0 update was released for older cards that supported only auto init DMA feature but not affected the playback rate.

There is firmware file in the original repository that has functionality of DSP 2.0 as I understand. Am I correct?

There are two additional firmwares sources - the 'original' one v 2.02 and one from the Chinese clone card.
Are both suitable for the Snark Barker card? What features do they have? That probably means "do they support 44.1kHz playback rate on Snark Barker"?

schlae, 2024-03-14:
Either will work on the Snark Barker. I don't believe any pre-2.0 DSP versions have been dumped, and both of these firmware files support the higher rate audio and auto init DMA.

Closed 2024-03-14.

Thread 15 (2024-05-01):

DSP ISSUE?

greukik, 2024-05-01:
Hello.

I just finished 2 cards and have the same issue.
Digit is not working. Sbdiag test runs well adlib cms.
Dsp adressing is pulsing on the oscillo. But dsp write test is not pulsing.
I found few people with the same issue on vogons.
I understand that the only common thing is the 89s51 from.mouser and programming from a t48. One important point is that checkid is blocking with a FF FF result and you have to disable checkid in order to flash. I'm not sure but I suspect something there...
Did you flash the atmel with a programmer or with isp method ?

schlae, 2024-05-02:
which DSP write test isn't pulsing? there are two parts:

1.  ISA_WR signal on U18 pin 8. this is generated by writes to the ISA bus and doesn't require a working 8051. but if this signal is not present, then it is a problem.
2.  DSP_RD signal on U18 pin 1. this is generated by the 8051. if the 8051 has issues then you will not see this pulse. if the ISA_WR signal isn't pulsing, then you will not see this pulse.

i typically flash using the TL866 not with ISP. getting a checkid result of FF FF on the t48 means that there is something wrong with the microcontroller. do you have the correct device selected in the programmer? is it in the socket the right way? (not shifted by one, rotated 180 degrees, etc).

greukik, 2024-05-02:
Thank you for you response and congrats for your fabulous work.
I have to precise that u18-1 is only 5v without any signal.
On u18-8 i have a nice regular triangle like signal.
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

greukik, 2024-05-15:
Hello. In ordrer to close this topic and help some people, I just received new ATMEL 89S52. 4 from 5 were fonctionnal and work well. So, my 5 atmel from mouser were ALL defective... Now I'm having fun. Thanks !

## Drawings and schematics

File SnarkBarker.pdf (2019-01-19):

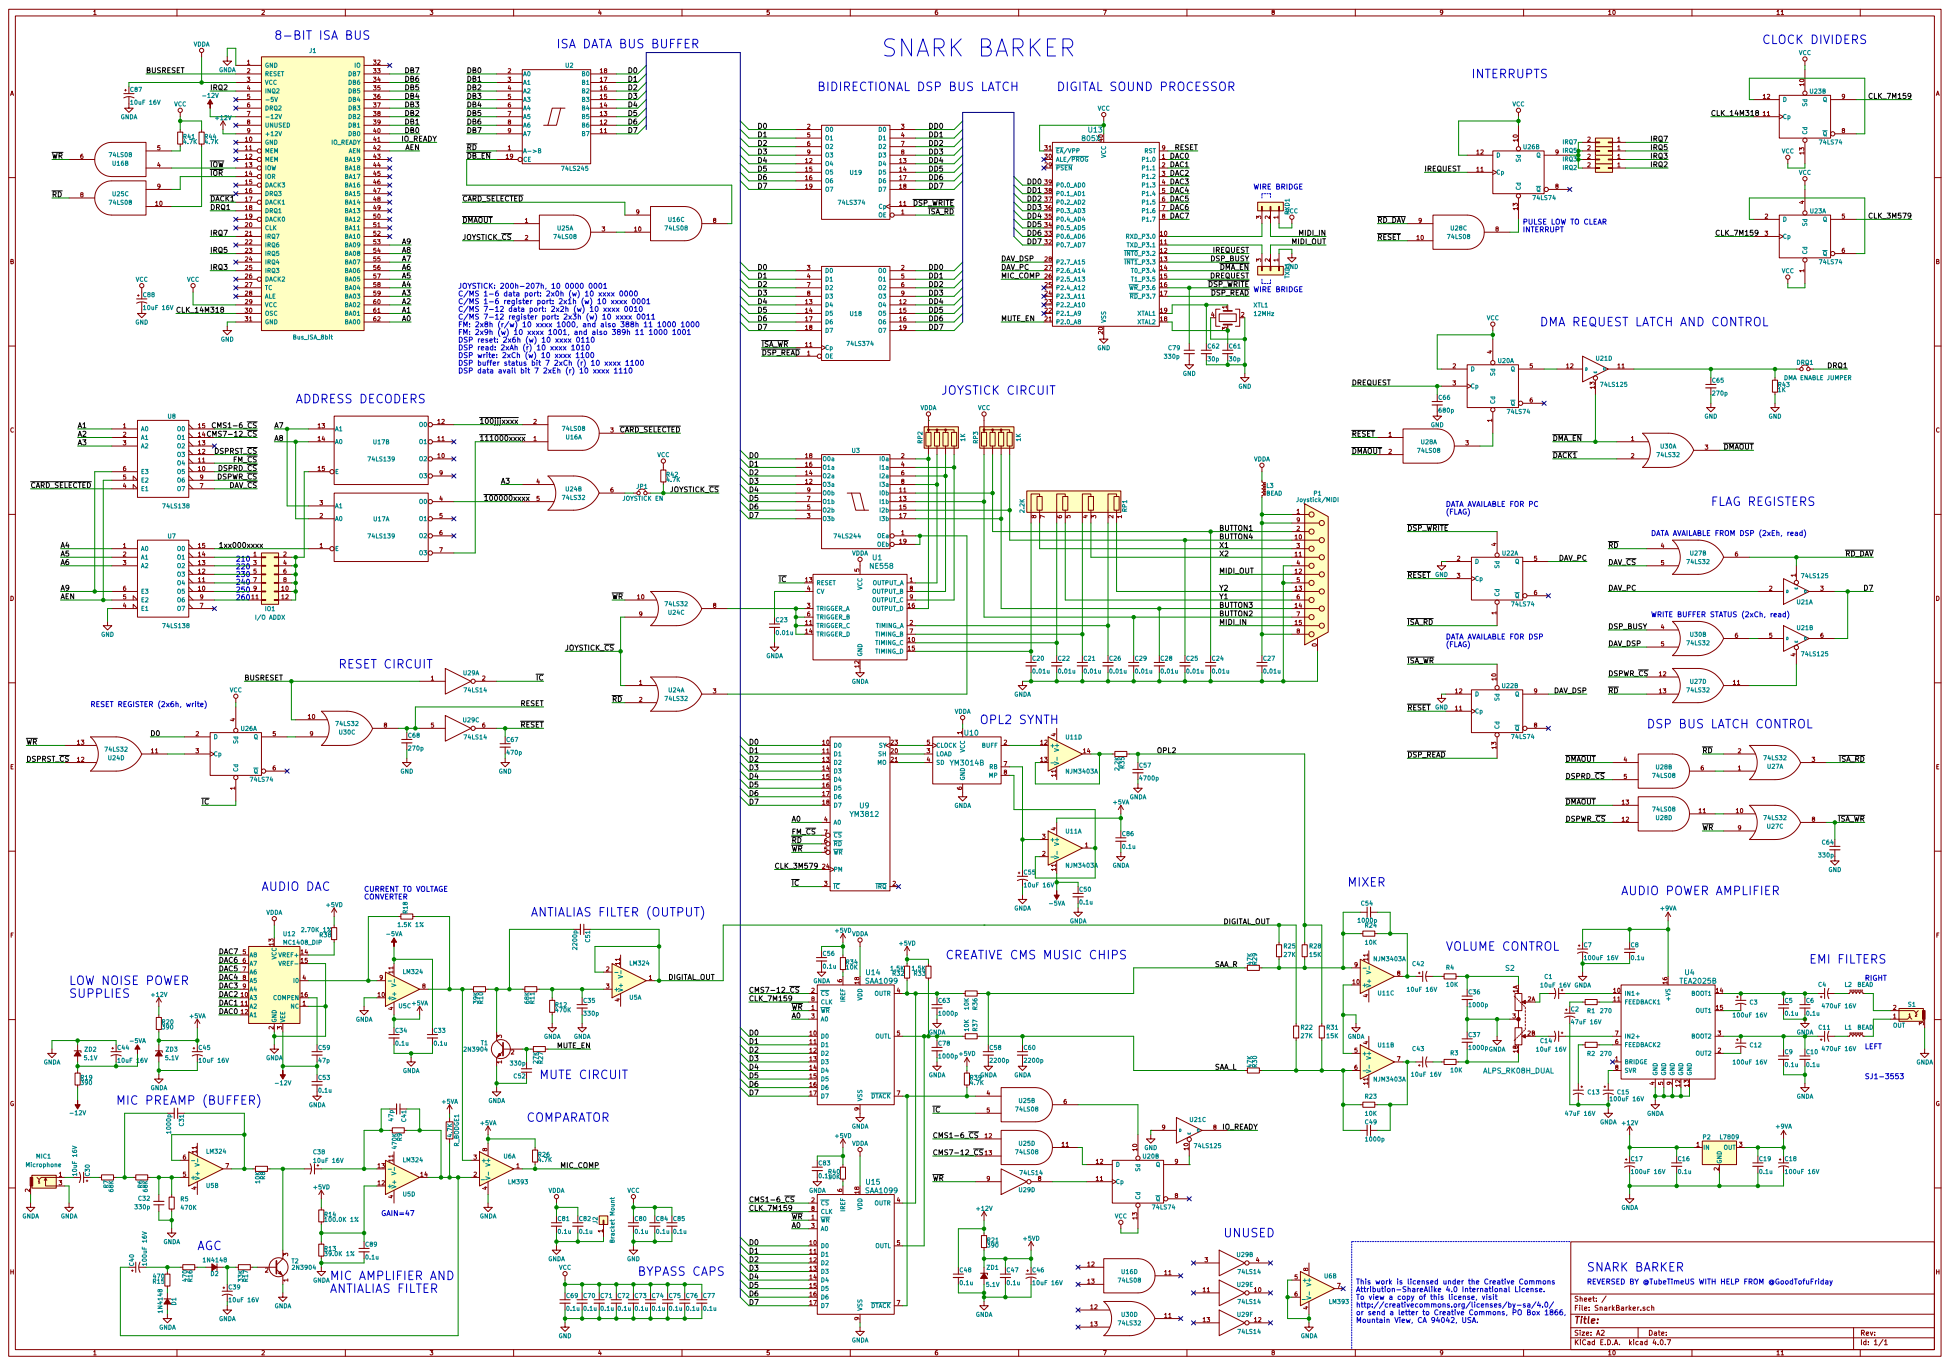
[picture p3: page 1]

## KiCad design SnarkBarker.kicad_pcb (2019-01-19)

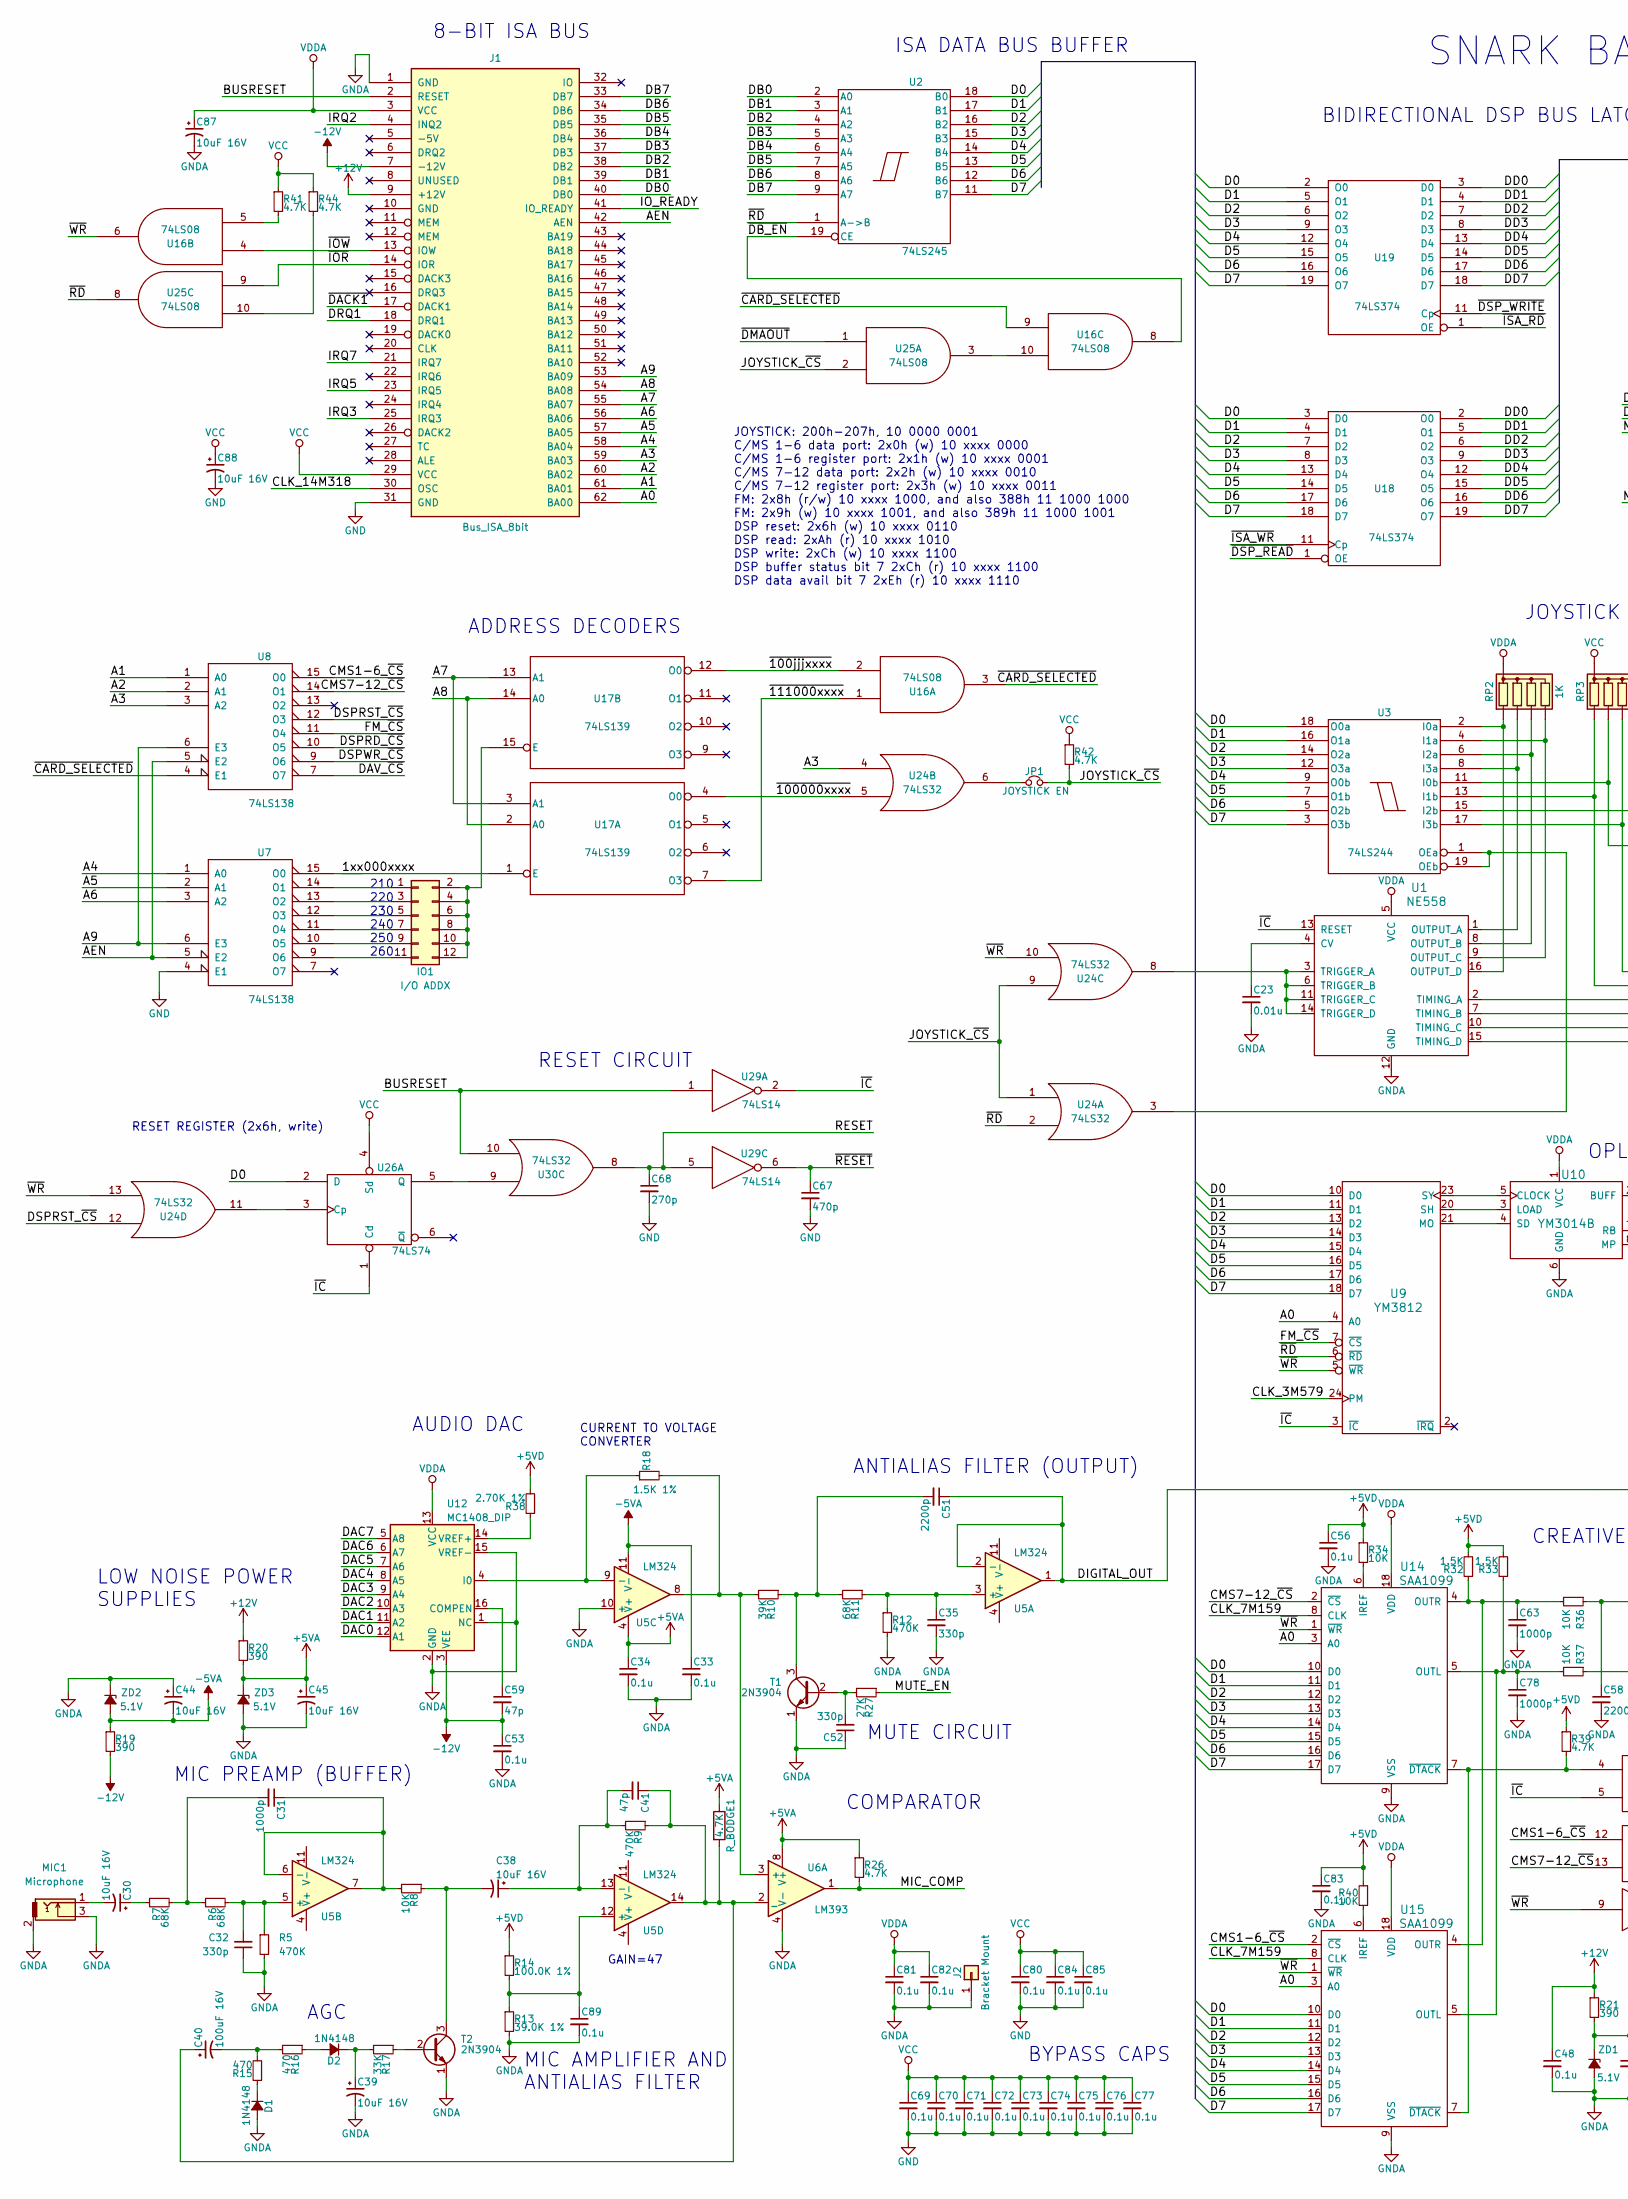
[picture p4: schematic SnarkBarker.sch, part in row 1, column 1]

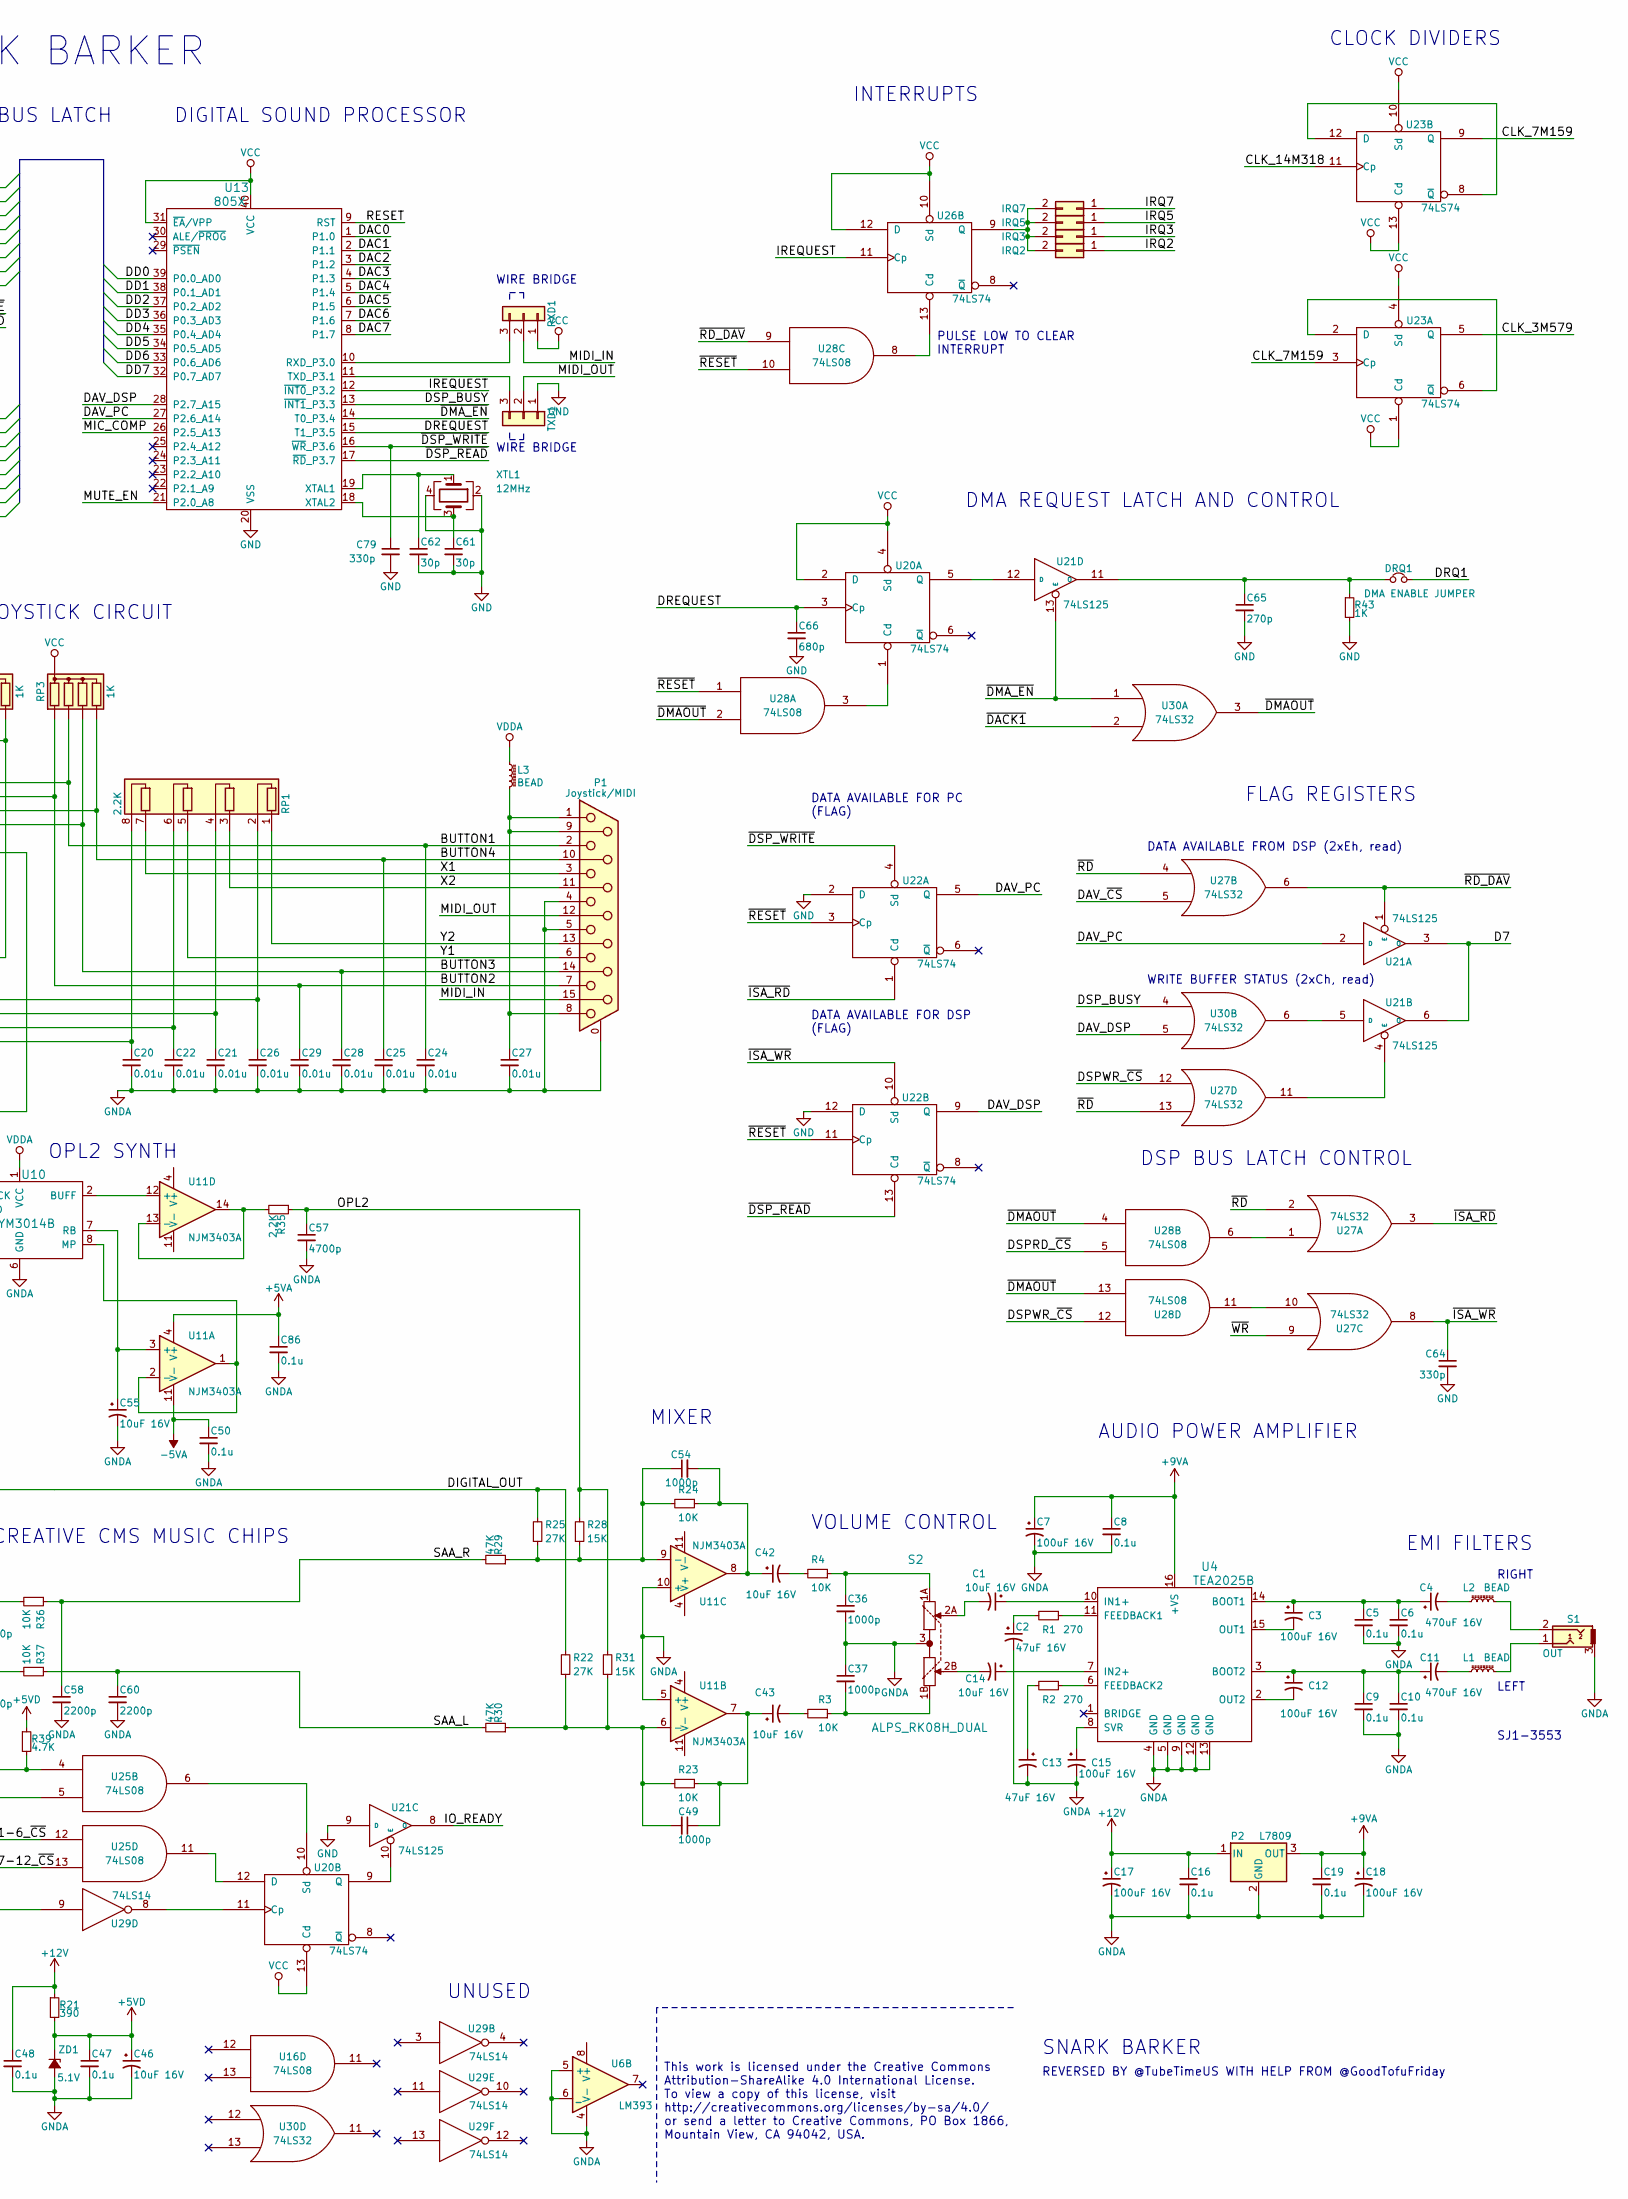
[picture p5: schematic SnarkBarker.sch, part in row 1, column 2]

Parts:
C1, C14, C30, C38, C39, C42, C43, C44, C45, C46, C55, C87, C88: 10uF 16V; SB_C_RADIAL_75_150; Mouser 667-ECA-1CM100I
C2, C13: 47uF 16V; SB_C_RADIAL_75_150; Mouser 667-ECA-1CM470I
C3, C7, C12, C15, C17, C18, C40: 100uF 16V; SB_C_RADIAL_100_320; Mouser 667-ECA-1CM101I
C4, C11: 470uF 16V; SB_C_RADIAL_100_320; Mouser 667-ECA-1CM471B
C5, C6, C8, C9, C10, C16, C19, C33, C34, C47, C48, C50, C53, C56, C69, C70, C71, C72, C73, C74, C75, C76, C77, C80, C81, C82, C83, C84, C85, C86, C89: 0.1u; SB_C_AXIAL_275; Mouser 581-SA105E104M
C20, C21, C22, C23, C24, C25, C26, C27, C28, C29: 0.01u; SB_C_DISC_200; Mouser 810-FG28X7R1H103KNT0
C31, C36, C37, C49, C54, C63, C78: 1000p; SB_C_DISC_200; Mouser 810-FG28X7R1H102KNT6
C32, C35, C52, C64, C79: 330p; SB_C_DISC_200; Mouser 810-FG28C0G1H331JNT6
C41, C59: 47p; SB_C_DISC_200; Mouser 810-FG28C0G1H470JNT6
C51, C58, C60: 2200p; SB_C_DISC_200; Mouser 810-FG28X7R1H222KNT6
C57: 4700p; SB_C_DISC_200; Mouser 810-FG28C0G1H472JNT6
C61, C62: 30p; SB_C_DISC_200; Mouser 810-FG28C0G1H270JNT6
C65, C68: 270p; SB_C_DISC_200; Mouser 810-FG28C0G1H271JNT0
C66: 680p; SB_C_DISC_200; Mouser 810-FG28C0G1H681JNT6
C67: 470p; SB_C_DISC_200; Mouser 810-FG28C0G1H471JNT6
D1, D2: 1N4148; SB_D_AXIAL_400; Mouser 512-1N4148
DRQ1: DMA ENABLE JUMPER; SB_HDR_1X2
IO1: I/O ADDX; SB_HDR_2X6
IRQ2, IRQ3, IRQ5, IRQ7: Conn_02x01; SB_HDR_1X2
J1: Bus_ISA_8bit; BUS_PC
J2: Bracket Mount; SB_MH_125; Mouser 534-9200
JP1: JOYSTICK EN; SB_HDR_1X2
L1, L2, L3: BEAD; SB_L_AXIAL_500; Mouser 623-2743004111
MIC1: Microphone; SB_MJ-3536N; Mouser 490-MJ-3536N
P1: Joystick/MIDI; SB_DB15_152-3415; Mouser 152-3415
P2: L7809; SB_TO220; Mouser 511-L7809CV
R1, R2: 270; SB_R_AXIAL_400; Mouser 603-CFR-25JB-52-270R
R3, R4, R8, R23, R24, R34, R36, R37, R40: 10K; SB_R_AXIAL_400; Mouser 603-CFR-25JB-52-10K
R5, R9, R12: 470K; SB_R_AXIAL_400; Mouser 603-CFR-25JR-52470K
R6, R7, R11: 68K; SB_R_AXIAL_400; Mouser 603-CFR-25JB-52-68K
R10: 39K; SB_R_AXIAL_400; Mouser 603-CFR-25JB-52-39K
R13: 39.0K 1%; SB_R_AXIAL_400; Mouser 603-MFR-25FBF52-39K
R14: 100.0K 1%; SB_R_AXIAL_400; Mouser 603-MFR-25FBF52-100K
R15, R16: 470; SB_R_AXIAL_400; Mouser 603-CFR-25JB-52-470R
R17: 33K; SB_R_AXIAL_400; Mouser 603-CFR-25JB-52-33K
R18: 1.5K 1%; SB_R_AXIAL_400; Mouser 603-MFR-25FBF52-1K5
R19, R20, R21: 390; SB_R_AXIAL_400; Mouser 603-CFR-25JB-52-390R
R22, R25, R27: 27K; SB_R_AXIAL_400; Mouser 603-CFR-25JB-52-27K
R26, R39, R41, R42, R44: 4.7K; SB_R_AXIAL_400; Mouser 603-CFR-25JB-52-4K7
R28, R31: 15K; SB_R_AXIAL_400; Mouser 603-CFR-25JB-52-15K
R29, R30: 47K; SB_R_AXIAL_400; Mouser 603-CFR-25JB-52-47K
R32, R33: 1.5K; SB_R_AXIAL_400; Mouser 603-CFR-25JB-52-1K5
R35: 2.2K; SB_R_AXIAL_400; Mouser 603-CFR-25JB-52-2K2
R38: 2.70K 1%; SB_R_AXIAL_400; Mouser 603-MFR-25FBF52-2K7
R43: 1K; SB_R_AXIAL_400; Mouser 603-CFR-25JR-521K
RP1: 2.2K; SB_RP_4B; Mouser 652-4608X-AP2-222LF
RP2, RP3: 1K; SB_RP_4C; Mouser 652-4605X-AP1-102LF
RXD1: Conn_01x03; SB_HDR_1X3
R_BODGE1: 4.7K; Mouser 603-CFR-25JB-52-4K7
S1: OUT; SB_SJ1-3553; Mouser 490-SJ1-3553NG
S2: ALPS_RK08H_DUAL; SB_ALPS_RK08_DUAL; Mouser 688-RK08H12100F3
T1, T2: 2N3904; SB_TO92; Mouser 833-2N3904-AP
TXD1: Conn_01x03; SB_HDR_1X3
U1: NE558; SB_DIP16_300
U2: 74LS245; SB_DIP20_300; Mouser 595-SN74LS245N
U3: 74LS244; SB_DIP20_300; Mouser 595-SN74LS244N
U4: TEA2025B; SB_DIP16_300
U5: LM324; SB_DIP14_300; Mouser 512-LM324AN
U6: LM393; SB_DIP8_300; Mouser 595-LM393P
U7, U8: 74LS138; SB_DIP16_300; Mouser 595-SN74LS138NE4
U9: YM3812; SB_DIP24_600
U10: YM3014B; SB_DIP8_300
U11: NJM3403A; SB_DIP14_300; Mouser 513-NJM3403AD
U12: MC1408_DIP; SB_DIP16_300; Mouser 926-DAC0808LCN/NOPB
U13: 805X; SB_DIP40_600; Mouser 556-A89S51-24PU
U14, U15: SAA1099; SB_DIP18_300
U16, U25, U28: 74LS08; SB_DIP14_300; Mouser 595-SN74LS08N
U17: 74LS139; SB_DIP16_300; Mouser 595-SN74LS139AN
U18, U19: 74LS374; SB_DIP20_300; Mouser 595-SN74LS374N
U20, U22, U23, U26: 74LS74; SB_DIP14_300; Mouser 595-SN74LS74AN
U21: 74LS125; SB_DIP14_300; Mouser 595-SN74LS125AN
U24, U27, U30: 74LS32; SB_DIP14_300; Mouser 595-SN74LS32N
U29: 74LS14; SB_DIP14_300; Mouser 595-SN74LS14N
XTL1: 12MHz; SB_XTAL_HC49U_RA; Mouser 815-AB-12-B2
ZD1, ZD2, ZD3: 5.1V; SB_D_AXIAL_400_ALT; Mouser 78-1N5231B-TAP

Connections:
+5VA: C34.1, C45.1, C86.1, R20.2, R26.1, R_BODGE1.1, U5.4 (V+), U6.8 (V+), U11.4 (V+), ZD3.1 (K)
+5VD: C46.1, C47.1, C56.1, C83.1, R14.1, R21.2, R32.2, R33.2, R34.1, R38.2, R39.1, R40.1, ZD1.1 (K)
+9VA: C7.1, C8.1, C18.1, C19.1, P2.3 (OUT), U4.16 (+VS)
+12V: C16.1, C17.1, C48.1, J1.9 (+12V), P2.1 (IN), R20.1, R21.1
-5VA: C33.1, C44.2, C50.1, R19.1, U5.11 (V-), U11.11 (V-), ZD2.2 (A)
-12V: C53.1, C59.2, J1.7 (-12V), R19.2, U12.3 (VEE)
/1xx000xxxx: U7.15 (O0), U17.1 (E)
/A0: J1.62 (BA00), U9.4 (A0), U14.3 (A0), U15.3 (A0)
/A1: J1.61 (BA01), U8.1 (A0)
/A2: J1.60 (BA02), U8.2 (A1)
/A3: J1.59 (BA03), U8.3 (A2), U24.4
/A4: J1.58 (BA04), U7.1 (A0)
/A5: J1.57 (BA05), U7.2 (A1)
/A6: J1.56 (BA06), U7.3 (A2)
/A7: J1.55 (BA07), U17.3 (A1), U17.13 (A1)
/A8: J1.54 (BA08), U17.2 (A0), U17.14 (A0)
/A9: J1.53 (BA09), U7.6 (E3), U8.6 (E3)
/AEN: J1.42 (AEN), U7.5 (E2), U8.5 (E2)
/BUSRESET: J1.2 (RESET), U29.1, U30.10
/BUTTON1: C24.1, P1.2, RP3.3 (R2), U3.11 (I0b)
/BUTTON2: C29.1, P1.7, RP3.2 (R1), U3.13 (I1b)
/BUTTON3: C28.1, P1.14, RP3.4 (R3), U3.17 (I3b)
/BUTTON4: C25.1, P1.10, RP3.5 (R4), U3.15 (I2b)
/CLK_3M579: U9.24 (PM), U23.5 (Q)
/CLK_7M159: U14.8 (CLK), U15.8 (CLK), U23.3 (Cp), U23.9 (Q)
/CLK_14M318: J1.30 (OSC), U23.11 (Cp)
/CMS1-6_~CS: U8.15 (O0), U15.2 (~CS), U25.12
/CMS7-12_~CS: U8.14 (O1), U14.2 (~CS), U25.13
/D0: U2.18 (B0), U3.18 (O0a), U9.10 (D0), U14.10 (D0), U15.10 (D0), U18.3 (D0), U19.2 (O0), U26.2 (D)
/D1: U2.17 (B1), U3.16 (O1a), U9.11 (D1), U14.11 (D1), U15.11 (D1), U18.4 (D1), U19.5 (O1)
/D2: U2.16 (B2), U3.14 (O2a), U9.13 (D2), U14.12 (D2), U15.12 (D2), U18.7 (D2), U19.6 (O2)
/D3: U2.15 (B3), U3.12 (O3a), U9.14 (D3), U14.13 (D3), U15.13 (D3), U18.8 (D3), U19.9 (O3)
/D4: U2.14 (B4), U3.9 (O0b), U9.15 (D4), U14.14 (D4), U15.14 (D4), U18.13 (D4), U19.12 (O4)
/D5: U2.13 (B5), U3.7 (O1b), U9.16 (D5), U14.15 (D5), U15.15 (D5), U18.14 (D5), U19.15 (O5)
/D6: U2.12 (B6), U3.5 (O2b), U9.17 (D6), U14.16 (D6), U15.16 (D6), U18.17 (D6), U19.16 (O6)
/D7: U2.11 (B7), U3.3 (O3b), U9.18 (D7), U14.17 (D7), U15.17 (D7), U18.18 (D7), U19.19 (O7), U21.3 (O), U21.6 (O)
/DAC0: U12.12 (A1), U13.1 (P1.0)
/DAC1: U12.11 (A2), U13.2 (P1.1)
/DAC2: U12.10 (A3), U13.3 (P1.2)
/DAC3: U12.9 (A4), U13.4 (P1.3)
/DAC4: U12.8 (A5), U13.5 (P1.4)
/DAC5: U12.7 (A6), U13.6 (P1.5)
/DAC6: U12.6 (A7), U13.7 (P1.6)
/DAC7: U12.5 (A8), U13.8 (P1.7)
/DAV_DSP: U13.28 (P2.7_A15), U22.9 (Q), U30.5
/DAV_PC: U13.27 (P2.6_A14), U21.2 (D), U22.5 (Q)
/DAV_~CS: U8.7 (O7), U27.5
/DB0: J1.40 (DB0), U2.2 (A0)
/DB1: J1.39 (DB1), U2.3 (A1)
/DB2: J1.38 (DB2), U2.4 (A2)
/DB3: J1.37 (DB3), U2.5 (A3)
/DB4: J1.36 (DB4), U2.6 (A4)
/DB5: J1.35 (DB5), U2.7 (A5)
/DB6: J1.34 (DB6), U2.8 (A6)
/DB7: J1.33 (DB7), U2.9 (A7)
/DD0: U13.39 (P0.0_AD0), U18.2 (O0), U19.3 (D0)
/DD1: U13.38 (P0.1_AD1), U18.5 (O1), U19.4 (D1)
/DD2: U13.37 (P0.2_AD2), U18.6 (O2), U19.7 (D2)
/DD3: U13.36 (P0.3_AD3), U18.9 (O3), U19.8 (D3)
/DD4: U13.35 (P0.4_AD4), U18.12 (O4), U19.13 (D4)
/DD5: U13.34 (P0.5_AD5), U18.15 (O5), U19.14 (D5)
/DD6: U13.33 (P0.6_AD6), U18.16 (O6), U19.17 (D6)
/DD7: U13.32 (P0.7_AD7), U18.19 (O7), U19.18 (D7)
/DIGITAL_OUT: C51.1, R22.2, R25.2, U5.1, U5.2 (-)
/DREQUEST: C66.1, U13.15 (T1_P3.5), U20.3 (Cp)
/DRQ1: DRQ1.2, J1.18 (DRQ1)
/DSPRD_~CS: U8.10 (O5), U28.5
/DSPRST_~CS: U8.12 (O3), U24.12
/DSPWR_~CS: U8.9 (O6), U27.12, U28.12
/DSP_BUSY: U13.13 (~INT1~_P3.3), U30.4
/FM_~CS: U8.11 (O4), U9.7 (~CS)
/IO_READY: J1.41 (IO_READY), U21.8 (O)
/IREQUEST: U13.12 (~INT0~_P3.2), U26.11 (Cp)
/IRQ2: IRQ2.1, J1.4 (INQ2)
/IRQ3: IRQ3.1, J1.25 (IRQ3)
/IRQ5: IRQ5.1, J1.23 (IRQ5)
/IRQ7: IRQ7.1, J1.21 (IRQ7)
/JOYSTICK_~CS: JP1.2, R42.2, U24.1, U24.9, U25.2
/MIC_COMP: R26.2, U6.1, U13.26 (P2.5_A13)
/MIDI_IN: P1.15, RXD1.2
/MIDI_OUT: P1.12, TXD1.2
/MUTE_EN: R27.1, U13.21 (P2.0_A8)
/OPL2: C57.1, R28.2, R31.2, R35.1
/RESET: C68.1, U13.9 (RST), U29.5, U30.8
/SAA_L: C60.1, R30.2, R37.1
/SAA_R: C58.1, R29.2, R36.1
/X1: P1.3, RP1.7 (R4.1)
/X2: P1.11 (P111), RP1.3 (R2.1)
/Y1: P1.6, RP1.5 (R3.1)
/Y2: P1.13, RP1.1 (R1.1)
/~100jjjxxxx: U16.2, U17.12 (O0)
/~100000xxxx: U17.4 (O0), U24.5
/~111000xxxx: U16.1, U17.7 (O3)
/~CARD_SELECTED: U8.4 (E1), U16.3, U16.9
/~DACK1: J1.17 (DACK1), U30.2
/~DB_EN: U2.19 (CE), U16.8
/~DMAOUT: U25.1, U28.2, U28.4, U28.13, U30.3
/~DMA_EN: U13.14 (T0_P3.4), U21.13 (E), U30.1
/~DSP_READ: U13.17 (~RD~_P3.7), U18.1 (OE), U22.13 (Cd)
/~DSP_WRITE: C79.1, U13.16 (~WR~_P3.6), U19.11 (Cp), U22.4 (Sd)
/~IC: U1.13 (RESET), U9.3 (~IC), U25.5, U26.1 (Cd), U29.2
/~IOR: J1.14 (IOR), U25.9
/~IOW: J1.13 (IOW), U16.4
/~ISA_RD: U19.1 (OE), U22.1 (Cd), U27.3
/~ISA_WR: C64.1, U18.11 (Cp), U22.10 (Sd), U27.8
/~RD: U2.1 (A->B), U9.6 (~RD), U24.2, U25.8, U27.2, U27.4, U27.13
/~RD_DAV: U21.1 (E), U27.6, U28.9
/~RESET: C67.1, U22.3 (Cp), U22.11 (Cp), U28.1, U28.10, U29.6
/~WR: U9.5 (~WR), U14.1 (~WR), U15.1 (~WR), U16.6, U24.10, U24.13, U27.9, U29.9
GND: C61.2, C62.2, C64.2, C65.2, C66.2, C67.2, C68.2, C69.2, C70.2, C71.2, C72.2, C73.2, C74.2, C75.2, C76.2, C77.2, C79.2, C80.2, C84.2, C85.2, C88.2, J1.31 (GND), R43.2, TXD1.1, U2.10 (GND), U3.10 (GND), U7.4 (E1), U7.8 (GND), U8.8 (GND), U9.12 (GND), U13.20 (VSS), U16.7 (GND), U17.8 (GND), U18.10 (GND), U19.10 (GND), U20.7 (GND), U21.7 (GND), U21.9 (D), U22.2 (D), U22.7 (GND), U22.12 (D), U23.7 (GND), U24.7 (GND), U25.7 (GND), U26.7 (GND), U27.7 (GND), U28.7 (GND), U29.7 (GND), U30.7 (GND), XTL1.2, XTL1.4
GNDA: C2.2, C5.2, C6.2, C7.2, C8.2, C9.2, C10.2, C13.2, C15.2, C16.2, C17.2, C18.2, C19.2, C20.2, C21.2, C22.2, C23.2, C24.2, C25.2, C26.2, C27.2, C28.2, C29.2, C32.1, C33.2, C34.2, C35.2, C36.2, C37.1, C39.2, C44.1, C45.2, C46.2, C47.2, C48.2, C50.2, C52.1, C53.2, C55.2, C56.2, C57.2, C58.2, C60.2, C63.2, C78.2, C81.2, C82.2, C83.2, C86.2, C87.2, C89.2, D1.2 (A), J1.1 (GND), J2.1, MIC1.2, MIC1.3, P1.0 (PAD), P1.4, P1.5, P2.2 (GND), R5.2, R12.2, R13.2, S1.3, S2.3, T1.1 (E), T2.1 (E), U1.12 (GND), U4.4 (GND), U4.5 (GND), U4.9 (GND), U4.12 (GND), U4.13 (GND), U5.10 (+), U6.4 (V-), U6.5 (+), U6.6 (_), U10.6 (GND), U11.5 (+), U11.10 (+), U12.1 (NC), U12.2 (GND), U12.15 (VREF-), U14.9 (VSS), U15.9 (VSS), ZD1.2 (A), ZD2.1 (K), ZD3.2 (A)
unnamed: C1.1, U4.10 (IN1+)
unnamed: C1.2, S2.2A
unnamed: C2.1, R1.2
unnamed: C3.1, C4.1, C5.1, C6.1, U4.14 (BOOT1)
unnamed: C3.2, U4.15 (OUT1)
unnamed: C4.2, L2.1
unnamed: C9.1, C10.1, C11.1, C12.1, U4.3 (BOOT2)
unnamed: C11.2, L1.1
unnamed: C12.2, U4.2 (OUT2)
unnamed: C13.1, R2.2
unnamed: C14.1, U4.7 (IN2+)
unnamed: C14.2, S2.2B
unnamed: C15.1, U4.8 (SVR)
unnamed: C20.1, RP1.8 (R4.2), U1.15 (TIMING_D)
unnamed: C21.1, RP1.4 (R2.2), U1.7 (TIMING_B)
unnamed: C22.1, RP1.6 (R3.2), U1.10 (TIMING_C)
unnamed: C23.1, U1.4 (CV)
unnamed: C26.1, RP1.2 (R1.2), U1.2 (TIMING_A)
unnamed: C27.1, L3.2, P1.1, P1.8, P1.9
unnamed: C30.1, R7.1
unnamed: C30.2, MIC1.1
unnamed: C31.1, R8.2, U5.6 (-), U5.7
unnamed: C31.2, R6.1, R7.2
unnamed: C32.2, R5.1, R6.2, U5.5 (+)
unnamed: C35.1, R11.1, R12.1, U5.3 (+)
unnamed: C36.1, R4.1, S2.1A
unnamed: C37.2, R3.1, S2.1B
unnamed: C38.1, C41.2, R9.2, U5.13 (-)
unnamed: C38.2, R8.1, T2.3 (C)
unnamed: C39.1, D2.1 (K), R17.2
unnamed: C40.1, C41.1, R9.1, R_BODGE1.2, U5.14, U6.2 (_)
unnamed: C40.2, R15.2, R16.2
unnamed: C42.1, C54.2, R24.1, U11.8
unnamed: C42.2, R4.2
unnamed: C43.1, C49.1, R23.1, U11.7
unnamed: C43.2, R3.2
unnamed: C49.2, R22.1, R23.2, R30.1, R31.1, U11.6 (-)
unnamed: C51.2, R10.1, R11.2, T1.3 (C)
unnamed: C52.2, R27.2, T1.2 (B)
unnamed: C54.1, R24.2, R25.1, R28.1, R29.1, U11.9 (-)
unnamed: C55.1, U10.7 (RB), U11.3 (+)
unnamed: C59.1, U12.16 (COMPEN)
unnamed: C61.1, U13.18 (XTAL2), XTL1.3
unnamed: C62.1, U13.19 (XTAL1), XTL1.1
unnamed: C63.1, R32.1, R36.2, U14.4 (OUTR), U15.4 (OUTR)
unnamed: C65.1, DRQ1.1, R43.1, U21.11 (O)
unnamed: C78.1, R33.1, R37.2, U14.5 (OUTL), U15.5 (OUTL)
unnamed: C89.1, R13.1, R14.2, U5.12 (+)
unnamed: D1.1 (K), R15.1
unnamed: D2.2 (A), R16.1
unnamed: IO1.1, U7.14 (O1)
unnamed: IO1.3, U7.13 (O2)
unnamed: IO1.5, U7.12 (O3)
unnamed: IO1.7, U7.11 (O4)
unnamed: IO1.9, U7.10 (O5)
unnamed: IO1.2, IO1.4, IO1.6, IO1.8, IO1.10, IO1.12, U17.15 (E)
unnamed: IO1.11, U7.9 (O6)
unnamed: IRQ2.2, IRQ3.2, IRQ5.2, IRQ7.2, U26.9 (Q)
unnamed: JP1.1, U24.6
unnamed: L1.2, S1.1
unnamed: L2.2, S1.2
unnamed: R1.1, U4.11 (FEEDBACK1)
unnamed: R2.1, U4.6 (FEEDBACK2)
unnamed: R10.2, R18.2, U5.8, U6.3 (+)
unnamed: R17.1, T2.2 (B)
unnamed: R18.1, U5.9 (-), U12.4 (I0)
unnamed: R34.2, U14.6 (IREF)
unnamed: R35.2, U11.13 (-), U11.14
unnamed: R38.1, U12.14 (VREF+)
unnamed: R39.2, U14.7 (~DTACK), U15.7 (~DTACK), U25.4
unnamed: R40.2, U15.6 (IREF)
unnamed: R41.2, U16.5
unnamed: R44.2, U25.10
unnamed: RP2.2 (R1), U1.16 (OUTPUT_D), U3.2 (I0a)
unnamed: RP2.3 (R2), U1.1 (OUTPUT_A), U3.8 (I3a)
unnamed: RP2.4 (R3), U1.8 (OUTPUT_B), U3.6 (I2a)
unnamed: RP2.5 (R4), U1.9 (OUTPUT_C), U3.4 (I1a)
unnamed: RXD1.3, U13.10 (RXD_P3.0)
unnamed: TXD1.3, U13.11 (TXD_P3.1)
unnamed: U1.3 (TRIGGER_A), U1.6 (TRIGGER_B), U1.11 (TRIGGER_C), U1.14 (TRIGGER_D), U24.8
unnamed: U10.2 (BUFF), U11.12 (+)
unnamed: U9.20 (SH), U10.3 (LOAD)
unnamed: U9.21 (MO), U10.4 (SD)
unnamed: U9.23 (SY), U10.5 (CLOCK)
unnamed: U10.8 (MP), U11.1, U11.2 (-)
unnamed: U16.10, U25.3
unnamed: U20.1 (Cd), U28.3
unnamed: U20.5 (Q), U21.12 (D)
unnamed: U20.9 (Q), U21.10 (E)
unnamed: U20.10 (Sd), U25.6
unnamed: U20.11 (Cp), U29.8
unnamed: U20.12 (D), U25.11
unnamed: U21.4 (E), U27.11
unnamed: U21.5 (D), U30.6
unnamed: U23.2 (D), U23.6 (~Q)
unnamed: U23.8 (~Q), U23.12 (D)
unnamed: U3.1 (OEa), U3.19 (OEb), U24.3
unnamed: U24.11, U26.3 (Cp)
unnamed: U26.5 (Q), U30.9
unnamed: U26.13 (Cd), U28.8
unnamed: U27.1, U28.6
unnamed: U27.10, U28.11
VCC: C69.1, C70.1, C71.1, C72.1, C73.1, C74.1, C75.1, C76.1, C77.1, C80.1, C84.1, C85.1, C88.1, J1.29 (VCC), R41.1, R42.1, R44.1, RP3.1 (common), RXD1.1, U2.20 (VCC), U3.20 (VCC), U7.16 (VCC), U8.16 (VCC), U9.1 (VCC), U13.31 (~EA~/VPP), U13.40 (VCC), U16.14 (VCC), U17.16 (VCC), U18.20 (VCC), U19.20 (VCC), U20.2 (D), U20.4 (Sd), U20.13 (Cd), U20.14 (VCC), U21.14 (VCC), U22.14 (VCC), U23.1 (Cd), U23.4 (Sd), U23.10 (Sd), U23.13 (Cd), U23.14 (VCC), U24.14 (VCC), U25.14 (VCC), U26.4 (Sd), U26.10 (Sd), U26.12 (D), U26.14 (VCC), U27.14 (VCC), U28.14 (VCC), U29.14 (VCC), U30.14 (VCC)
VDDA: C81.1, C82.1, C87.1, J1.3 (VCC), L3.1, RP2.1 (common), U1.5 (VCC), U10.1 (VCC), U12.13 (VCC), U14.18 (VDD), U15.18 (VDD)

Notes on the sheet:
BYPASS CAPS
210 220 230 240 250 260
AGC
MIC PREAMP (BUFFER)
MIC AMPLIFIER AND ANTIALIAS FILTER
GAIN=47
CURRENT TO VOLTAGE CONVERTER
AUDIO DAC
MUTE CIRCUIT
ANTIALIAS FILTER (OUTPUT)
COMPARATOR
MIXER
VOLUME CONTROL
AUDIO POWER AMPLIFIER
EMI FILTERS
LEFT
RIGHT
LOW NOISE POWER SUPPLIES
OPL2 SYNTH
CREATIVE CMS MUSIC CHIPS
JOYSTICK CIRCUIT
CLOCK DIVIDERS
PULSE LOW TO CLEAR INTERRUPT
JOYSTICK: 200h-207h, 10 0000 0001 C/MS 1-6 data port: 2x0h (w) 10 xxxx 0000 C/MS 1-6 register port: 2x1h (w) 10 xxxx 0001 C/MS 7-12 data port: 2x2h (w) 10 xxxx 0010 C/MS 7-12 register port: 2x3h (w) 10 xxxx 0011 FM: 2x8h (r/w) 10 xxxx 1000, and also 388h 11 1000 1000 FM: 2x9h (w) 10 xxxx 1001, and 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
FLAG REGISTERS
INTERRUPTS
DMA REQUEST LATCH AND CONTROL
ISA DATA BUS BUFFER
RESET CIRCUIT
DATA AVAILABLE FOR PC (FLAG)
DATA AVAILABLE FOR DSP (FLAG)
DATA AVAILABLE FROM DSP (2xEh, read)
WRITE BUFFER STATUS (2xCh, read)
RESET REGISTER (2x6h, write)
8-BIT ISA BUS
DIGITAL SOUND PROCESSOR
BIDIRECTIONAL DSP BUS LATCH
DSP BUS LATCH CONTROL
ADDRESS DECODERS
UNUSED

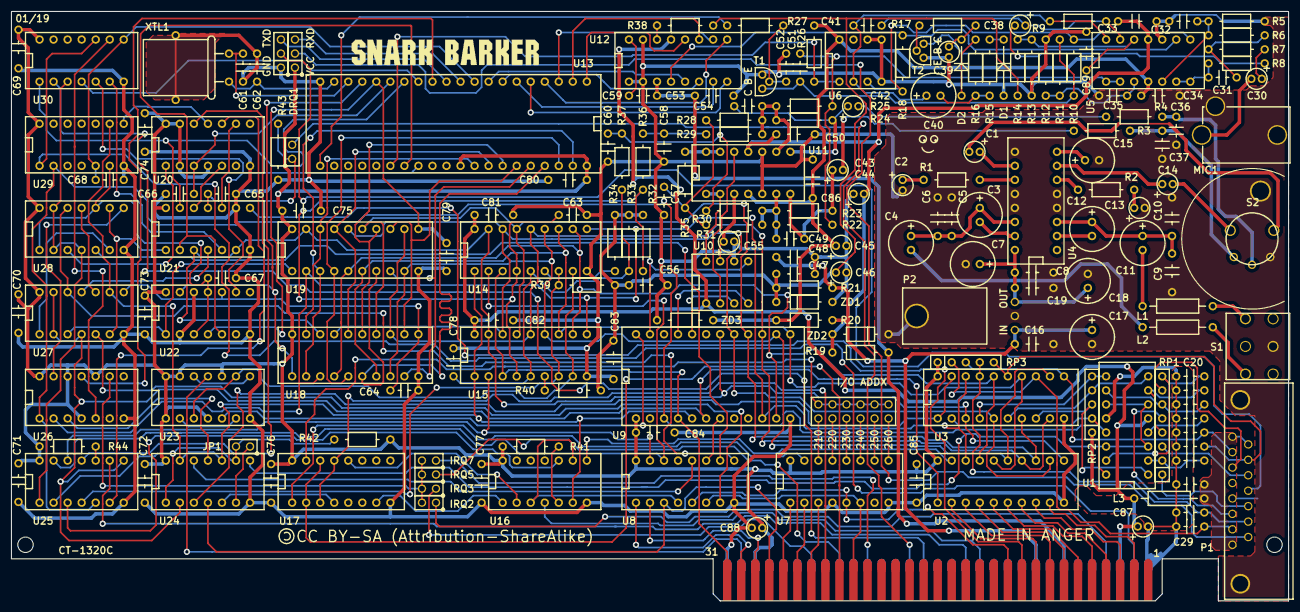
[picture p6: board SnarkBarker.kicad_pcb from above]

Board: 2 copper layers, 231.1 x 106.7 mm, 193 parts (0 on the bottom side), 215 nets.

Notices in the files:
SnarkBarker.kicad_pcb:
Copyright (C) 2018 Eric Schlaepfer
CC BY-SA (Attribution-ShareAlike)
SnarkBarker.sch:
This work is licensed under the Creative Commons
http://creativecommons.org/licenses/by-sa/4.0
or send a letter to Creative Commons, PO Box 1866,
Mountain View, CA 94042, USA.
